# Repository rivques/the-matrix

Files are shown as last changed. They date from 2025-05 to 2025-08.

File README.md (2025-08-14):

# the-matrix



This is a large (theoretically 1ftx1ft) LED matrix display with a resolution of up to 120x120 monochrome pixels. My intended use for it is to act as an "ultra-clock," showing not just the time but also other useful information like weather, sports scores, maybe news, etc. However, it should be said that this is designed to be a generic module, and not destined for any specific project - this should be something I can pull off my shelf, send the correct control signals to, and get a display from.

I've had the ultra-clock idea for a while, and I originally wanted to use flip dots for the display, but they turned out to be expensive and hard to find, so I switched to using LED matrices instead.

The full display is constructed of 9 display modules, each of which itself contains 25 8x8 LED matrices. Each module also contains positions for the shift registers and MOSFETs that make up the control circuitry.

However, I have not yet built the full display - scaling up from 1 to 9 modules turned out to be _much_ harder than expected. I have 4 modules fully built, plus harnesses and a control board - I just haven't been able to make them play nice, despite spending more than 20 hours on scaling and troubleshooting. I still hope to realize the full vision at some point, but I'm pretty burnt out on this for the short term.

The display is not without its quirks. Most of these stem from either the geometric realities of trying to fit everything onto the board or a software-compensatable routing mistake that would take hours of work to fix in hardware. The biggest of these is that the current-limiting resistors aren't actually on the board but instead fly above the back of it. Also, the bottom and top row of matrices on each module are rotated 90 degrees, and every other module has pairs of rows and columns swapped (e.g. col1 connects to col2, col2->col1, col3->col4, etc.) This is something I can fix in software.

The display will probably be driven by a Pi Pico W or an ESP32, but especially if high framerates are not required it could be also driven by something less powerful. The driver connects to each row and column via the row control and column control pads.

One of the things I hope to learn from this board is where the limits actually lie when I try to drive things at high frequencies. I don't know how scared to be of things like ringing or EMI, and I'll probably find out.

The theoretical max framerate for this board is something like 4096fps, which would probably be implemented as 16fps with 255-tick BCM dimming, though this would require driving the clock line at something like 4MHz, and I have no idea if that'll be possible. If it's not, I can derate to something like 8fps with 7-tick dimming, which would be ~64fps or a much more manageable 60kHz clock frequency.

Here's a render of the back of the a single display module (the front is just a grid of matrices, which I don't have a 3D model for but I'm sure you can imagine). For more pictures, including the schematic and each internal layer, check out the [journal](https://github.com/rivques/the-matrix/blob/main/JOURNAL.md#may-29th).


BOM (for some parts I'm getting spares since they'd be a pain to source if some turn out to be dead on arrival. if this can't be included in the grant i'll happily cover the spares myself):

Part|Quantity|Price/unit|Total price|# pins/unit|# pins total|Note|Link
---|---|---|---|---|---|---|---
788AS 8x8 LED Matrix|230|$0.35|$82.00|16|3600|not going to count on 0% DoA rate here|https://www.aliexpress.us/item/2251832771187101.html
74HC595 Shift Register|15|$0.22|$4.00|16|240|2x20 is cheaper than 3x5|https://www.aliexpress.us/item/3256807421796895.html
TPIC6B595 Shift Register|20|$0.50|$10|16|240|again, not counting on no DoA|https://www.aliexpress.us/item/3256806981485001.html
IRFU9024NPBF MOSFET|125|$0.40|$40.00|3|360||https://www.aliexpress.us/item/3256808251284284.html
220Ω Resistor|120|$0.02|$2.80|2|240|2x100 is cheaper than 12x10|https://www.aliexpress.us/item/2251832766343175.html
2x20 right-angle header female|12|$2.00|$4.00|40|80||https://www.aliexpress.us/item/3256805899201197.html
2x20 right-angle header male|12|$2.50|$5.00|40|80||https://www.aliexpress.us/item/3256804718416281.html
5V 3A Power Supply|1|$4.00|$4.00|2|2||https://www.aliexpress.us/item/3256805577151044.html
Matrix PCB|10|$2.5|$25.00|0|0|i'll buy this separately from the grant so i can combine it with another order|JLCPCB
Total|||$173||4850|total w/o PCB: $148 :tada:

Schematic:


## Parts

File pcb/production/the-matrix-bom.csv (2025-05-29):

Id | Designator | Footprint | Quantity | Designation | Supplier and ref
1 | DS5,DS3,DS18,DS2,DS6,DS12,DS1,DS19,DS22,DS25,DS8,DS17,DS16,DS13,DS9,DS11,DS4,DS15,DS24,DS23,DS20,DS7,DS14,DS21,DS10 | DISPLAY_TA08-81GWA | 25 | TA08-81GWA
2 | Q13,Q6,Q26,Q39,Q36,Q11,Q22,Q38,Q33,Q14,Q5,Q15,Q10,Q28,Q17,Q21,Q34,Q31,Q9,Q24,Q3,Q16,Q4,Q29,Q25,Q30,Q37,Q1,Q7,Q18,Q8,Q32,Q40,Q27,Q20,Q19,Q12,Q23,Q2,Q35 | TO-251-3_Vertical_ThinPads | 40 | Q_PMOS_GDS
3 | U6,U8,U9,U10,U7 | DIP-20_W7.62mm | 5 | TPIC6B595N
4 | J6,J5 | PinSocket_2x20_P2.54mm_Horizontal | 2 | Conn_02x20_Odd_Even
5 | U3,U4,U1,U2,U5 | DIP-16_W7.62mm | 5 | 74HC595
6 | J4,J3 | PinHeader_2x20_P2.54mm_Horizontal | 2 | Conn_02x20_Odd_Even
7 | J2 | PinHeader_1x10_P2.54mm_Vertical | 1 | DNP
8 | J1 | PinHeader_1x13_P2.54mm_Vertical | 1 | DNP

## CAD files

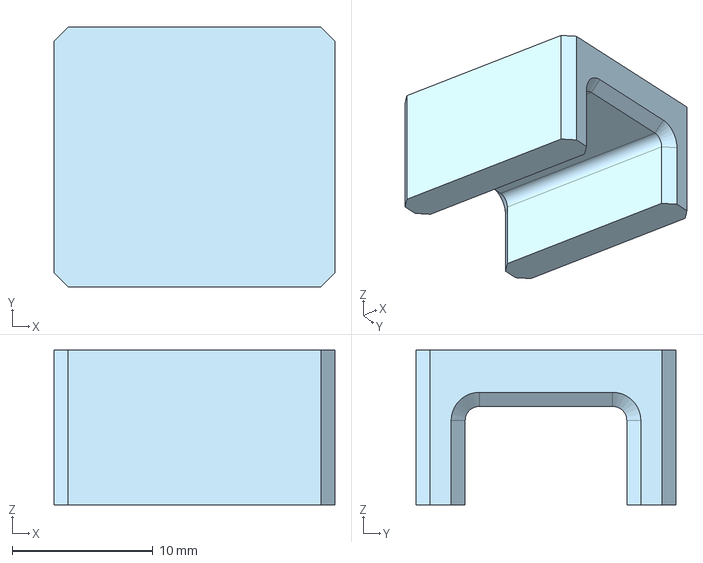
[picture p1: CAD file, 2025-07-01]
pcb/production/display_soldering_tool.step
20.0 x 18.5 x 11.0 mm

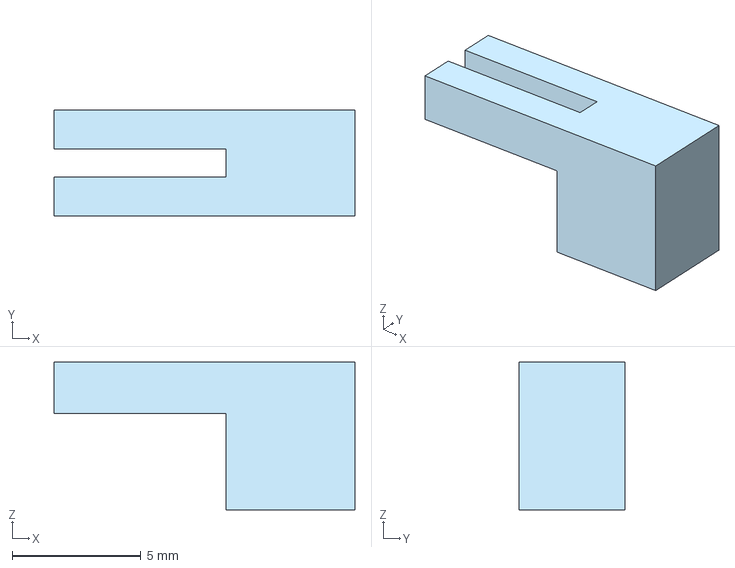
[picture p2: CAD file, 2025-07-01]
pcb/production/mosfet tool.step
11.7 x 4.10 x 5.74 mm

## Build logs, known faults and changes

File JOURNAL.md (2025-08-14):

---
title: "The Matrix"
author: "rivques"
description: "A large LED matrix to display things like the time, weather, sports scores, etc."
created_at: "2025-05-27"
---
## total time thru end of May: 17 hours
# May 27th:
Ok so this is something I've wanted to make for a while: a kind of "super-clock" that shows not just the time but also other relevant information. Initially I wanted to use flip-dot displays, but those are expensive and hard to find, so I'm pivoting to an LED matrix. I want to put a bunch of [these cheap 8x8 displays](https://www.aliexpress.us/item/2251832771187101.html) together, right now I'm thinking 30x30cm, which is 15x15=225 displays or 120x120=1440 pixels. The raw cost of those displays would be ~$80. I'm trying to figure out driver ICs. Ideally I'd like to solder everything myself, with no tiny SMD parts. One option is a bunch (30-450) of 74HC595s, depending on how many displays I want to be able to control at once. Let's take a second to do the math of how many LEDs/second I need to update to get, say, 10fps:
```numbat
let target = 10 fps
unit leds
let num_leds = 15*15*64leds
let leds_per_second = num_leds/frame*target
    = 144_000 leds/s
```
Okay. So say I go with the minimum of 30 74HC595s, and I update one column of the screen at a time. At 3V3 the max clock frequency is something like 25MHz, so let's see if 1MHz is enough:
```numbat
let clock_freq = 1 MHz
let columns_per_second = clock_freq/120
    = 8333 columns/s
let frames_per_second = columns_per_second/120
    ~70 fps
```
That's actually very good! And if I can actually hit 10MHz then I could get 700fps which might even be enough to do some PWM (BCM?) dimming, and that's assuming I have all the shift registers daisy-chained together and am not driving them in paralell. And another reason why that's great is that it makes my current needs low, if I'm only lighting a max of 120 leds at a time. So that would put my current needs at:
```numbat
let leds_per_column = 120 leds
let current_per_led = 12mA/led
let current_per_column = leds_per_column*current_per_led
    = 1.44 A
```
And since I'm only using one column at a time, that power is very manageable! I'll probably need to put a transistor on each column and row, because the 74HC595s can only source 6mA per pin, and I'd like to hit more like 12 or 14. So I'll need 240 transistors and 120 resistors, which won't be fun to solder, but shouldn't be too bad.

...

okay, i've done some more research, and it looks like it might make sense to switch to something like the TPIC6B595 for the low side, since it can sink enough current without needing a transistor. 

And then to fit it within the JLC PCB size I'll make a bunch of smaller boards that hook together with like right-angle duponts.

OK so here's what the major components are looking like right now:
Part|Quantity|Price/unit|Total price|# pins/unit|# pins total|Link
---|---|---|---|---|---|---
788AS 8x8 LED Matrix|225|$0.35|$80.00|16|3600|https://www.aliexpress.us/item/2251832771187101.html
74HC595 Shift Register|15|$0.22|$4.00|16|240|https://www.aliexpress.us/item/3256807421796895.html
TPIC6B595 Shift Register|15|$0.50|$7.50|16|240|https://www.aliexpress.us/item/3256806981485001.html
IRF9520 MOSFET|120|$0.40|$48.00|3|360|https://www.aliexpress.us/item/3256806868594722.html
220Ω Resistor|120|$0.02|$2.80|2|240|https://www.aliexpress.us/item/2251832766343175.html
5V 3A Power Supply|1|$4.00|$4.00|2|2|https://www.aliexpress.us/item/3256805577151044.html
Matrix PCB|10|$2.20|$22.00|0|0|JLCPCB
Total|||$164||4700|

Okay, $164 isn't terrible. What I'm more concerned about is 4700 joints, that'll take a while. Rounding up to 5000 for the connectors and stuff, if I can do 40 joints per minute (optimistic), that'll take:
```numbat
unit joints
5000 joints / (40 joints/minute)
    = 125 minutes
```
...that's not as bad as I thought. It'll probably end up being twice that, but I was afraid it'd be something like 40 hours. This project seems feasible!

**total time spent (estimate): 2.5 hours**: 

# May 27th, part 2:
OK i'm going to sit down and try to work out a schematic. I also realized that I needed to switch to a P-channel MOSFET for the high side, which I changed in the BOM.

[much later]

ok so there's a schematic now. i decided im not going to have a separate PCB for the control board, i'll just do that on perfboard. (again, bom has been updated). so now the plan is to make 9 (well, 10, because of JLC order sizing) boards to _almost_ the schematic. each board will be populated with its 25 displays and the 4 40 pin connectors, and then one board in each row/column will have that row/colum's driving circuitry. Then the board with driving circuitry will be connected to the control board, which will have a pi pico w on it. next up: routing this monstrosity. i'll have to make sure i don't make impossible sandwhiches, but other than that it shouldn't be difficult, just tedious.

## screenshots

## close-up on one matrix and drivers


**total time spent (estimate): 3 hours**

# May 27th, part 3:
start time: 11pm

ok i'm going to start on the pcb layout. I'm not ghoing to try to do routing tonight, but i do want to at least get the rough positions of things figured out.

ok, i'm about 30 mins in, and its becoming clear that i have to rotate the top and bottom rows of displays 90 degrees so i can fit the row connectors in. this will cause some headaches when doing the firmware, but i don't think i have a choice. this is what it's looking like now:



ok now for the (hopefully easier!) task of shoving all the ics and mosfets under the displays.

...and i'm realizing that there's no way to do this without 4 layers. fortunately it's not that much mre expensive.

30 more minutes later, these mosfets are just way too big. i'm going to switch to the [IRFU9024NPBF](https://www.aliexpress.us/item/2251832086805199.htm), which is actually cheaper than my original option, and it's in the smaller TO-251 package.

...it's been another 30 minutes, and i've gotten everything placed, thanks to the smaller mosfets. here's what it's looking like:



and that may not look terrible, but keep in mind that almost every empty pad is going to have an led matrix in it from the other side, and that's not even considering the traces between the near-1000 pads on this board. if this is possible, it's possible by the slimmest of margins.

**total time spent: 1.5 hours**
**total time on May 27th: 7 hours**

# May 28th:
Start time: 9am
Okay I'm starting to route the rows to each other. I'm changing the footprint of the mOSTFETS slightly to allow a trace to fit between their pads.

[one hour later]

so i've gotten the middle rows and the rght column and a half routed. it's difficult but not impossible. the top and bottom rows are going to be a massive pain since they're rotated.

[another hour later]

Ok, i have all of the matrices routed, using just the internal layers. I haven't routed the connectors or drivers yet, but hopefully the outer layers are enough room for that. here's what it looks like now:



**total time spent: 2 hours**

# May 28th, part 2:
Start time: 2:45pm
I'm going to start routing the connectors. Hopefully I can stay on the interal layers, but I'm okay to use the outer ones sparingly.

[one hour later]

okay, one connector and some of the mosfets are routed. i've needed the outer layers 3 times so far - not as bad as I was expecting!

[another hour later]

ok, another connector and the rest of the mosfets' column connections are routed. next up: the row connectors.

...this is _really_ annoying routing.

...ok i've routed the left row connector. i'll do the right one later.

**total time spent: 2.5 hour**
# May 28th, part 3:
Start time: 8:30pm
ok time to do the last connector and then hopefully the last part won't be that bad.

[30 minutes later]

i've just realized that i set up the connectors wrong in the schematic, so row 1 would connect to row 2 and vice versa, row3<->row4, etc, same with columns. either i can give up the past 3 hours of work, or i can spend a similar amount of time fixing that in software. let me think for a second about that:
ok so the way this would manifest is just in the display, it wont cause any electrical issues fortunately. it'd just be that the middle row/column of matrices would have their column pairs swapped with each other. i wonder how i can efficiently represent that in software.

well i'm going to have to have a preprocessing step for every frame i want to display. and i'll leave it up to later me to figure out what the best way to swap the columns and rotate the displays is there, i'd rather spend 3 hours programming than 3 hours rerouting stuff i've already done once, and it'll hopefully take less than 3 hours to fix. it's unfortunate, but oh well.

anyways back to routing the last of the right connector, yipee!

[another 30 minutes later]

ok, all connectors complete! now the only thing left is just hooking up the shift registers, and i have almost all of the outer layers to make it happen. here's how it's looking now:



ok now i'm going to hook the mosfets up to the shift registers

[30 minutes later]
ok the mosfets are connected to the low-shift registers. now i need to connect the rows to the low-side shift registers, connect the shift register data lines to each other, and give power to everything.

[15 mins later]

all shift registers are connected to their matrices/mosfets. next: data lines.

[15 mins later]
ok the low-side data lines were pretty quick, because there's patterns between the chips. i've done the data lines on 1 high-side driver and they were super annoying - they're long and there's no patterns from chip to chip. i'm going to call it a night.

**total time spent: 2 hours**
**total time on May 28th: 6.5 hours**
# May 29th:
Start time: 9am
Time to finish up the data lines.

[45 minutes later]

That wasn't so bad. Now my only remaining unrouted nets are power and ground!

[30 minutes later]

ok, power and ground are routed, and I learned that fills don't need pre-existing traces in order to automatically connect to nets, so that saved me a lot of work. Time to run DRC and see how bad everything is.

...413+ errors. oh boy.

okay, so ~200 of those were because i'd input the JLC via size constraints (confused via diameter with annular width), so those went away. Most of the rest were because of me putting pads under the displays, which was by design. Then there were a few which were about short traces being unconnected, which I'm ignoring, and a bunch of silkscreen overlap, which I will now go fix.

WAIT I RAN THE SCHEMATIC PARITY CHECK AND SOMEWHERE ALONG THE WAY I FULLY DELETED A DISPLAY
ok time to trawl thru the git history and find when that happened

ok it was in the last commit so hopefully i can just put it back and things will be fine

yeah it turned out fine. i must have deleted it right before running drc. phew.

anyways time to go mess with silkscreens

[30 minutes later]

ok, I _think_ the board is complete! Here are some screenshots:
||
---|---|---
||
||

going to export the gerbers and get a real price!

ok so it's $9 for the boards (with a coupon), plus $16 shipping. i can't believe how cheap JLC is.

and just going to do a revised bill of materials here:
(for some parts I'm getting spares since they'd be a pain to source if some turn out to be dead on arrival. if this can't be included in the grant i'll happily cover the spares myself)

Part|Quantity|Price/unit|Total price|# pins/unit|# pins total|Note|Link
---|---|---|---|---|---|---|---
788AS 8x8 LED Matrix|230|$0.35|$82.00|16|3600|not going to count on 0% DoA rate here|https://www.aliexpress.us/item/2251832771187101.html
74HC595 Shift Register|15|$0.22|$4.00|16|240|2x20 is cheaper than 3x5|https://www.aliexpress.us/item/3256807421796895.html
TPIC6B595 Shift Register|20|$0.50|$10|16|240|again, not counting on no DoA|https://www.aliexpress.us/item/3256806981485001.html
IRFU9024NPBF MOSFET|130|$0.40|$50.00|3|360||https://www.aliexpress.us/item/3256806868594722.html
220Ω Resistor|120|$0.02|$2.80|2|240|2x100 is cheaper than 12x10|https://www.aliexpress.us/item/2251832766343175.html
2x20 right-angle header female|2|$2.00|$4.00|40|80||https://www.aliexpress.us/item/3256805899201197.html
2x20 right-angle header male|2|$2.50|$5.00|40|80||https://www.aliexpress.us/item/3256804718416281.html
5V 3A Power Supply|1|$4.00|$4.00|2|2||https://www.aliexpress.us/item/3256805577151044.html
Matrix PCB|10|$2.5|$25.00|0|0|i'll buy this separately from the grant so i can combine it with another order|JLCPCB
Total|||$173||4850|total w/o PCB: $148 :tada:

i think this is almost ready to ship!  
**total time spent: 3.5 hours**

# June 26th:
Start time: 4pm

OK some of the parts have started to arrive. I'm realizing I'm going to need to make a tool to hold the displays in the right place while I solder them, so I'm going to grab the 3D model and throw it in Onshape and see what I can do.

ok, i've got the model in Onshape (and I added a model of the matrix module itself), and I've started to sketch out a magazine page. The holder will have to wait for tomorrow.

**total time spent: 1 hour**
# June 27th:
Start time: 11:15am

just nearly finished the magazine page. it took a while but i'm not used to figma. one weird thing i ended up doing was to get a render of the board with a transparent background, I rendered it in KiCad, then remove the background with remove.bg, but that only gave a low-quality version, so I pulled it into GIMP, and used the transparency as a mask on the high-quality render.

**total time spent: 1 hour**

# June 30th:
Start time: 4pm

All my parts arrived!

I 3D printed some little feet that I can use while soldering to hold the board at the correct height. 

I'm going to start by soldering the bare minimum support components for a single display (DS1) and go from there. That includes, in order:

- U1
- U6
- Q1-Q8
- DS1
- R1-R8

Hmm, by not doing the whole board at once I'll make it much more annoying to solder the rest of the backside components. I think it's worth it to be able to test the first display, though. 

As a side note, the order for an entire module will be:
- U1-U5
- U6-U10 (with outputs cut)
- J1-J6 as needed
- Q1-Q40
- DS1-DS25
- R1-R40

[45 mins later]
aaa i forgot to cut the outputs on U6, so i've had to cut the physical traces, which is luckily possible but is still a pain.

[45 mins later]
i'm almost there! i've just got 3 jumper resistors left, which are, predictably, the most annoying part. i don't look forward to doing 115 more of them.

**total time spent: 1.5 hours**

# June 30th, part 2:
Start time: 9:45pm

time to solder the last 3 resistors, then i'll write some test code

[30 mins later]  
resistors soldered! behold (but not too closely):  


ok tomorrow we wire it up and start testing!  
**total time spent: 30 mins**  
**total time on June 30th: 2 hours**  

# July 1st:
Start time: 12:30pm

time to start on code. i'll start with full software driving, not PIO, while i test things at low FPS.

[an hour later]

i've wired everything up and written some test code and... it's not working. it seems like i'm doing something wrong with at least the low-side shift register, because when i short one of its outputs to ground i do get leds turning on. the voltages on its output pins are either 5 volts (which is reasonable for open-drain state) or 3 volts (which is not reasonable, especially if that's it trying to sink current). it's not unlikely that i broke the chip while soldering, but i'm hoping it's not that. i'm going to write a super simple test program and try to isolate the problem.

[45 mins later]  
so there's also something wrong with the high-side. i'm focusing on that one first - it seems to be totally unresponsive to my commands.  
i found it - i just miswired the column control header. hopefully that fixes many of the problems.
and also it looks like i've partially miswired the row control header as well.

[15 mins later]  
ok, rewiring complete, and it looks like that helped a lot, but not all the way. going to keep messing with the test program.

[15 mins later]  
ok i think i've isolated the issue to the low side. (column 3 has a bad solder joint too, but that's not the main issue). for some reason, the shift register just isn't listening to me. i'm going to take a break, but I think the next step is to triple-check the pinout and then the datasheet if that doesn't work.

**total time spent: 2.25 hours**

# July 1st, part 2:
Start time: 6pm

no apparent wiring issue. time to check the datasheet.  
i see a problem! in the schematic, I mixed up RCK and SRCK (labeling them as ROWCLK and ROWLATCH instead of the other way around). Let me try swapping them back in my wiring...  
progress! now one row of LEDs lights up!  
AND IT ALMOST FULLY LIGHTS WHEN I RUN THE RIGHT TEST CODE!

the one remaining issue is that COL3 isn't illuminating. I'm going to reflow the solder joints really quick and see if that helps.  
it didn't fix it. Time to play more of everyone's favorite game "where's the voltage?"  
...actually, i just reflowed the wrong joint. Reflowing the correct joint fixed it!

ok, time to test some other stuff. First up: PWMing the ROWEN pin for global brightness control.  
...yep, works perfectly.

briefly, here's the current list of the various ways in which this is janky:
- need to use 3D resistor technology to connect the low side shift registers
- need to use display height jigs + solder from top to fit around the expansion ports
- row latch and clock pins are the wrong way around on the schematic

next: try to drive it in PIO, and hopefully fix some of the flickering i'm seeing which I assume is from micropython's garbage collection or similar.

... no luck on the first attempt at PIO, but there's so many things that could be wrong. I'm going to pare it down to a minimal example and build it back up.

... ok i worked out a bunch of bugs. now the only thing left is something weird with the ring size parameter on the DMA. maybe i need to align the buffer to memory or smth? anyways its a problem for later. one thing that helped a lot was putting LEDs on most of the outputs so I could see what I was trying to do. then it was just a matter of tweaking the various parameters of the PIO stuff (set_init ordering, transfer size, byte swapping, etc.) until it worked.

**total time spent: 2.5 hours**

# July 1st, part 3:
Start time: 10:30pm

Against my better judgment I'm going to keep working on this tonight. I have some ideas for how to fix the ring size issue.

[30 mins later]  
IT WORKS! like, fully works! the trick was to just have an interrupt run whenver the DMA write was done that immediately restarted it. I ran into some weirdness where the board refused to enumerate on USB once I uploaded the file, but a flash_nuke.uf2 fixed that. Now to see how far I can push the PIO frequency...  
looks like 2MHz has some slight ghosting - like the rows stay on for a little while the next column is written, but 1MHz is fine. Working backwards, that equates to:
```numbat
let pio_clk = 1MHz
let col_rate = pio_clk/52
let full_bw_rate = col_rate/120
    = 160 fps
```
That's... a little lower than I hoped. It means I might not be able to get any greyscale values without getting flickering. But there's definetly room for optimization, I bet if I adjust the timings in the PIO program I can figure out which delay is critical to eliminating ghosting and which I can speed up. Now, though, I think the next step is to solder up another matrix module and try to get two working together. This is looking really promising!

**total time spent: 30 mins**
**total time on July 1st: 5.25 hours**

# July 2nd
start time: 3:30 pm

OK with yesterday's success I'm going to solder the rest of the high-side components to expand to a 8x40 display.

[1 hour later]

that was 32 transistors, 4 shift registers, and 4 displays in ~1 hour, or a little under 4 joints per minute. That's a bit slow, but hopefully working in bigger batches will help.

Now, i'm going to adjust the code to account for the 32 new columns, which should be pretty trivial

[1.25 hours later]
...it was not pretty trivial. there were a few solder joints i needed to reflow, but then micropython started being weird - like claiming the pio was running, then not actually running it except for the 0.1secs when i pressed ctrl+c, and disconnecting from the repl fixed the issue.

[15 mins later]

i spent some time trying to make a function to draw a framebuf on the screen, but i had a bad approach. i'll try again later.

**total time spent: 2.5 hours**

# July 9th:
Start time: 1pm

The goal for today is to get one full module working. So I need to solder:
- U7-U10 (with outputs cut)
- J5 and J6
- DS10-DS25
- R9-R40

[4 hours later]

soldering complete! again, the resistors were incredibly annoying. I do think it won't be _that_ bad to solder the non-row-control modules.

Going to update the code to use a 40x40 display, and see how it works.

[1 hour later]

updated the code, and it mostly works! there's a few display joints that need reflowing, some of which will be a massive pain to reach, but by and large it works! next: figuring out what transform each display needs to be in the right place. 

[another hour later]

got all the pins reflowed! there's some glitchiness with some pixels flickering, not sure why that is yet. my next step is probably to try and optimize the framebuf->pio data step - right now it takes 1700ms(!) and if i can get that to like <50ms then i can do some animations.

here's what it looks like now:  


**total time spent: 6 hours**

# July 10th:
start time: 11:30am

I'm trying to optimize the frame computation. So far I've gotten it from 1700ms to 450ms by precomputing the transformation from display x/y space to bit in framebuf. I shaved off another 50ms by adjusting for loops to move through the LUT sequentially. Finally, I got down to ~325ms by using the `@micropython.native` decorator, which is very cool. I might be able to get a little more if I made the function work with the `viper` optimizing compiler. I think that's the end of the easy wins, though. If I want, say, 50ms, then each pixel would only get 7 instructions to deal with, and that's if I overclocked to 200MHz. That seems unfeasible. Part of what makes this difficult is that it's hard to operate on more than 1 bit at a time. I can't operate on, say a byte of the framebuf (an 8-pixel row of the display) at a time, because the PIO needs column-first indexing, so I'd span 8 columns. Even if I switched the framebuffer format to column-first, I'd still have issues because adjacent pixels end up in separate PIO words. I think maybe I need to admit that I won't get realistic realtime frame computation, so I'll need to precompute frames that need to play at more than 2fps. That'll cost (16 bytes per column * 120 columns) = a little under 2 KiB per frame. With a `gc.collect()`, the board reports ~160 KiB free, or 80 frames. Not sure how much of that will end up taken by the networking stack, but even so, I can't think of many clock faces that would even need precomputation, and those that do wouldn't need more than ~10. So this should be fine.

As an aside, I'm getting an understanding for how a GPU gets its speedup. This pixel-by-pixel work is so succeptible to parallelization (on a per-column basis at the very least), but I don't have 120 cores handy to do it.

**total time spent: 1 hour**

# July 22nd:
Start time: 11am

Getting back to this project after Undercity, I'm going to solder another display module, to be attached horizontally. This means I'll need to solder:
- U1-U5
- J2, J4-J6
- Q1-Q40
- DS1-DS25

[2 hours later]

I finished the module! I haven't tested it yet, though. It looks like I didn't quite judge the spacing right on the inter-module connectors, there's ~1px of space between modules. Also, I was doing some more theorizing about the max frame computation speed - that 7 cyc/pixel number is way off, at 50ms frame times it's more like 350cyc/px, which is much more manageable.

**total time spent: 2 hours**

# July 23rd:
Start time: 1:30pm

Going to see if the new module works.

[30 mins later]

ok i keep trying to wire these jumpers onto a breadboard and it's so messy and i keep miswiring things. i'm going to start on the control board for the real thing so i can do the wiring once and for all.

ok so here are the connections:

pin | # connections
---|---
5V | 6-12
GND | 12-18 (bc colen is pulled low)
CLR | 6
LATCH | 6
ROWEN | 3
ROWCLK | 3
COLCLK | 3
COLDAT | 1
ROWDAT0-14 | 1 each

i'm going to have to do splices for the main lines, there's no way i'm running 50 wires back to a control box.

ok time to go sketch 

something like this?



not sure how i'm going to mount these yet. maybe i'll make a backplane that uses the gap between modules and hooks onto the connectors? btw i weighed a module and it was 144g.

oh also maybe i could use those 40-pin connectors i have for the connections to the controller?

** total time spent: 1 hour**

# July 24th:
Start time: 12:30pm

Going to design the wiring harness that will connect the modules to the controller. 
So the row harness will run vertically down the side of the display and will carry 22 wires. It'll connect to the controller with a spare 2x20 header, and will branch into three 1x12 headers for the three rows. The following lines will be spliced so all modules share them: 5V, ROWCLK, CLEAR, LATCH, ROWEN, and 2xGND. Then each connector will also get 5 ROWDAT lines. The column harness will have a similar, but simpler structure. It'll connect to the controller with a 1x8 header, and will branch into three 1x10 headers for the three columns. The following lines will be spliced so all modules share them: 2x5V, COLCLK, CLEAR, LATCH, and GND. The COLDAT line will be daisy-chained along the harness. The COLEN pin will be tied to the other GND pin at the header. 

**total time spent: 30 mins**

# July 26th:
Start time: 10:45am

Pinout for row connector:
1|2|3|4|5|6|7|8|9|10|11|12|13|14|15|16|17|18|19|20
---|---|---|---|---|---|---|---|---|---|---|---|---|---|---|---|---|---|---|---
ROWEN/GP0|ROWDAT0/GP1|GND|ROWDAT1/GP2|ROWDAT2/GP3|ROWDAT3/GP4|ROWDAT4/GP5|GND|ROWDAT5/GP6|ROWDAT6/GP7|ROWDAT7/GP8|ROWDAT8/GP9|GND|ROWDAT9/GP10|ROWDAT10/GP11|ROWDAT11/GP12|ROWDAT12/GP13|GND|ROWDAT13/GP14|ROWDAT14/GP15
5V|NC|NC|NC|NC|NC|NC|NC|NC|NC|NC|NC|NC|NC|NC|ROWCLK/GP19|CLEAR/GP18|NC|LATCH/GP17|NC

Pinout for column connector:
1|2|3|4|5|6|7|8
---|---|---|---|---|---|---|---
COLDAT/GP16|LATCH/GP17|GND|CLEAR/GP18|NC|COLCLK/GP20|5V|5V

Other connections:
- 5V rail to pico VSYS
- GND rail to pico GND
- Power jack to power rails

[1:45 later]
protoboard complete (except for the power jack). I think what's next is just grinding through the rest of the modules.

Just gonna paste the order of operations here:
- U1-U5
- U6-U10 (with outputs cut)
- J1-J6 as needed
- Q1-Q40
- DS1-DS25
- R1-R40

**total time spent: 2 hours**

# July 26th, part 2:
Start time: 4:30pm

[1.5 hours later]
All done with the (0, 1) module except for the resistors. After that, I get to do my first driverless module, which will be interesting.

**total time spent: 1.5 hours**
**total time on July 26th: 3.5 hours**

# July 28th
Start time: 11am

Time to grind through a bunch of modules. Resistors, then the first driverless module, then the (2, 0) column driver, then another driverless.

[2 hours later]

That was an annoyingly long time soldering resistors. Hopefully the rest will go faster.

[1 hour later]

Driverless module complete. Time for the harness, forr real this time,.

[1.5 hours later]

Column harness wires stripped and soldered, with one connector out of 4 complete. 

**total time spent: 4.5 hours**

# July 29th:
Start time: 9am

Adding the connectors to the column harness.

[1 hour later]

Column harness complete! Time for the row harness.

[3 hours later]

Row harness nearly complete - just need to solder the 1x12s. Then, _hopefully_, I can just plug in the display modules and it will Just Work.

**total time spent: 4 hours**

# August 9th
Start time: 11am

Time to solder the last of the row harness.

[1 hour 45 minutes later]

Row harnesses complete. When we come back: moment of truth.

**total time spent: 1 hour 45 minutes**

# August 10th
Start time: 10:45pm

It's not working, the second column is full on. 

[15 minutes later]

I've switched the COLEN and the COLDATOUT pins on the harness connectors. I'll have to re-solder them and deal with how to tie COLEN low. That'll be really annoying.

**total time spent: 15 minutes**

# August 11th
Start time: 12:45pm

I've swapped the COLDAT lines to the correct pins on the harness connectors, and tied COLEN to GND with bodge wires on each board. I also fixed a few other bad solder joints on the connectors - I really wish I'd designed this in a way that let me use an off-the-shelf harness to connect things. I'm still having issues. Something is wrong with the communication to the row controllers - the specific row data isn't being received correctly, regardless of clockspeed. rows 0-3 on each module are either all on or all off depending on what the majority of the bitmap is, and row 4 is doing its own random thing.

I'm pretty close to burning out on this project, I've been in the trenches for so long and I haven't gotten any new things working for more than a month - I've just been laying the groundwork needed for scaling. 

**total time spent: 1 hour**

# August 13th
Start time: 11:45am

I'm going to reduce scope to just one module so that I don't burn out and so that I have something to submit. This should be as easy as just running my existing code.

[1 hour 45 minutes later]



I got it working again! One of the things I forgot about was mixing up latch and clock signals, so once I fixed that I was able to do a bit of programming to allow displaying successive frames and it pretty much just worked.

Next: a last-ditch attempt to make the 4-module version work.

**total time spent: 1 hour 45 minutes**

# August 13th, part 2
Start time: 7:15pm

Ok, perhaps ill-advisedly, I'm going to try to scale back up to 2x2. But I think I know what the issue was this time: ROWCLK and ROWLATCH being swapped. To fix this, I'm re-solder the protoboard to swap that back.

[30 minutes later]

All boards light, but the 3 off-main ones definetly are not healthy. There are soooo many things that could have gone wrong there, and I don't think I have time to figure out which one.



**total time spent: 30 minutes**
**total time on August 13th: 2 hours 15 minutes**

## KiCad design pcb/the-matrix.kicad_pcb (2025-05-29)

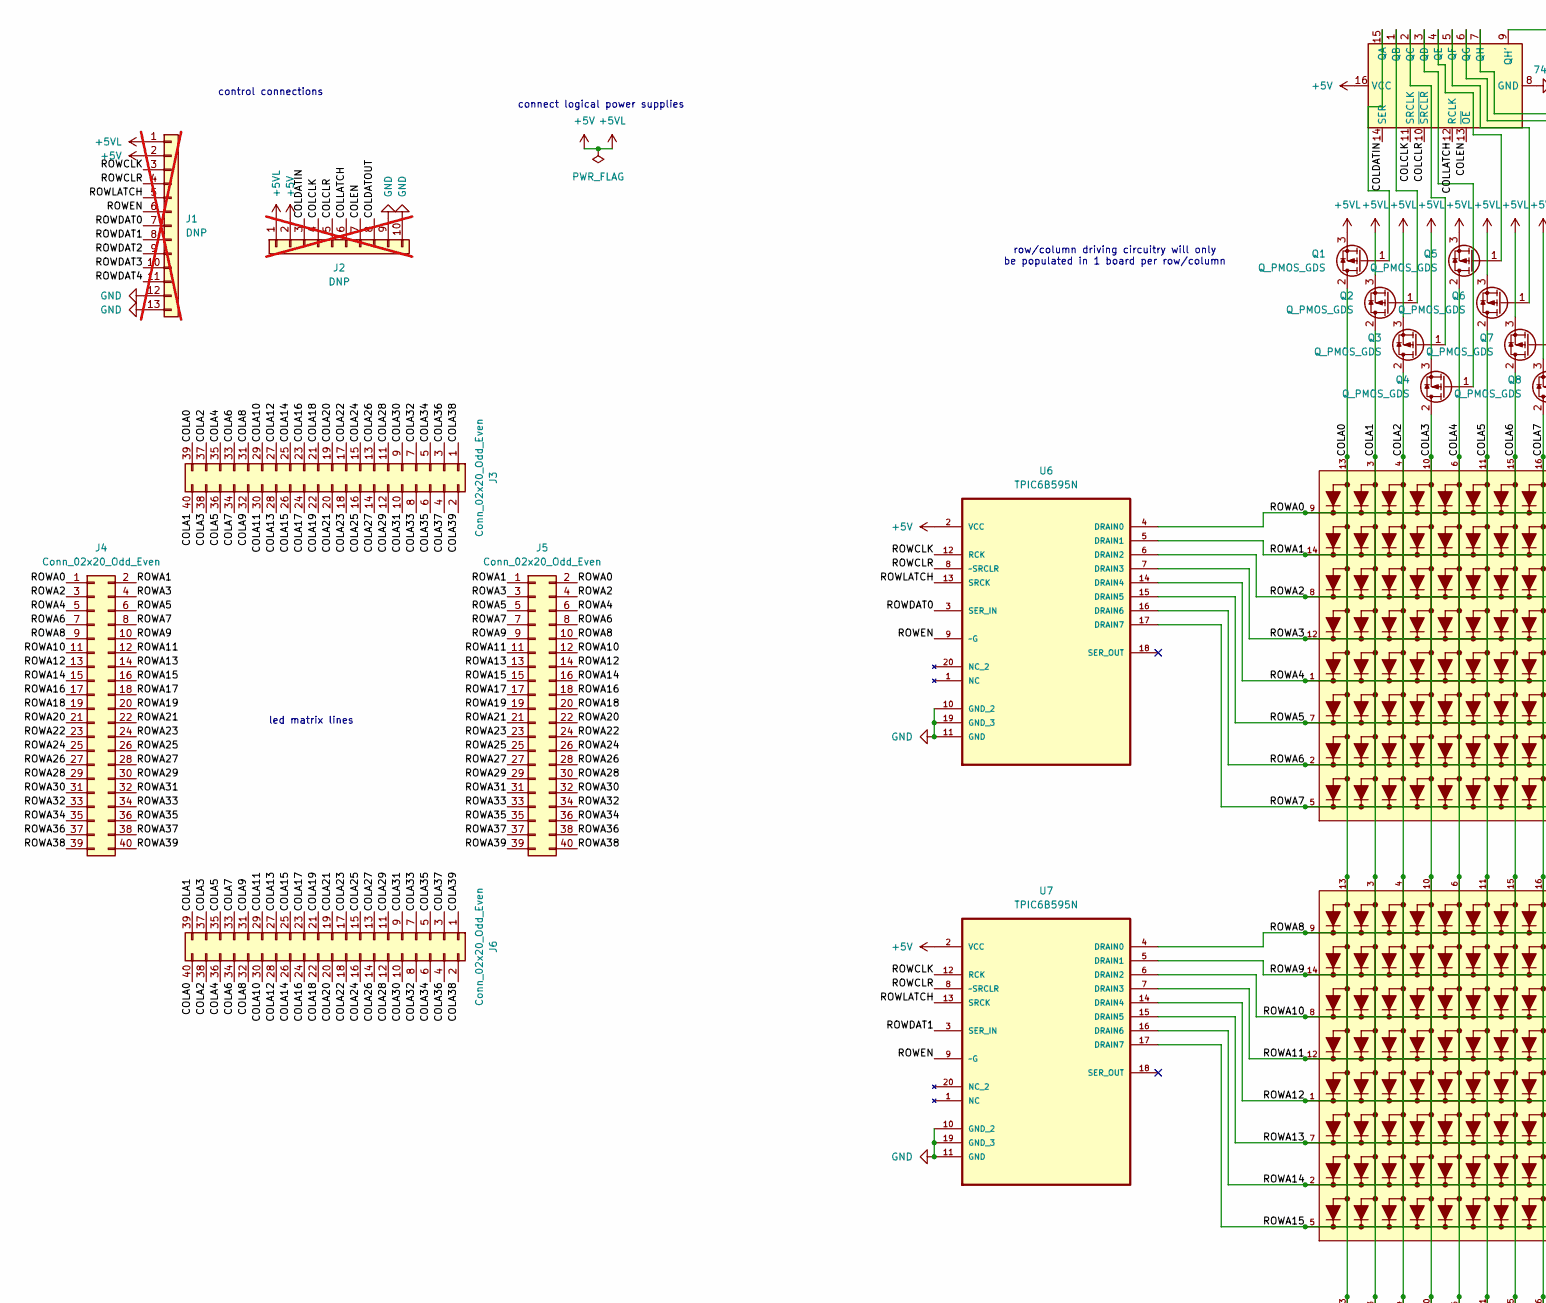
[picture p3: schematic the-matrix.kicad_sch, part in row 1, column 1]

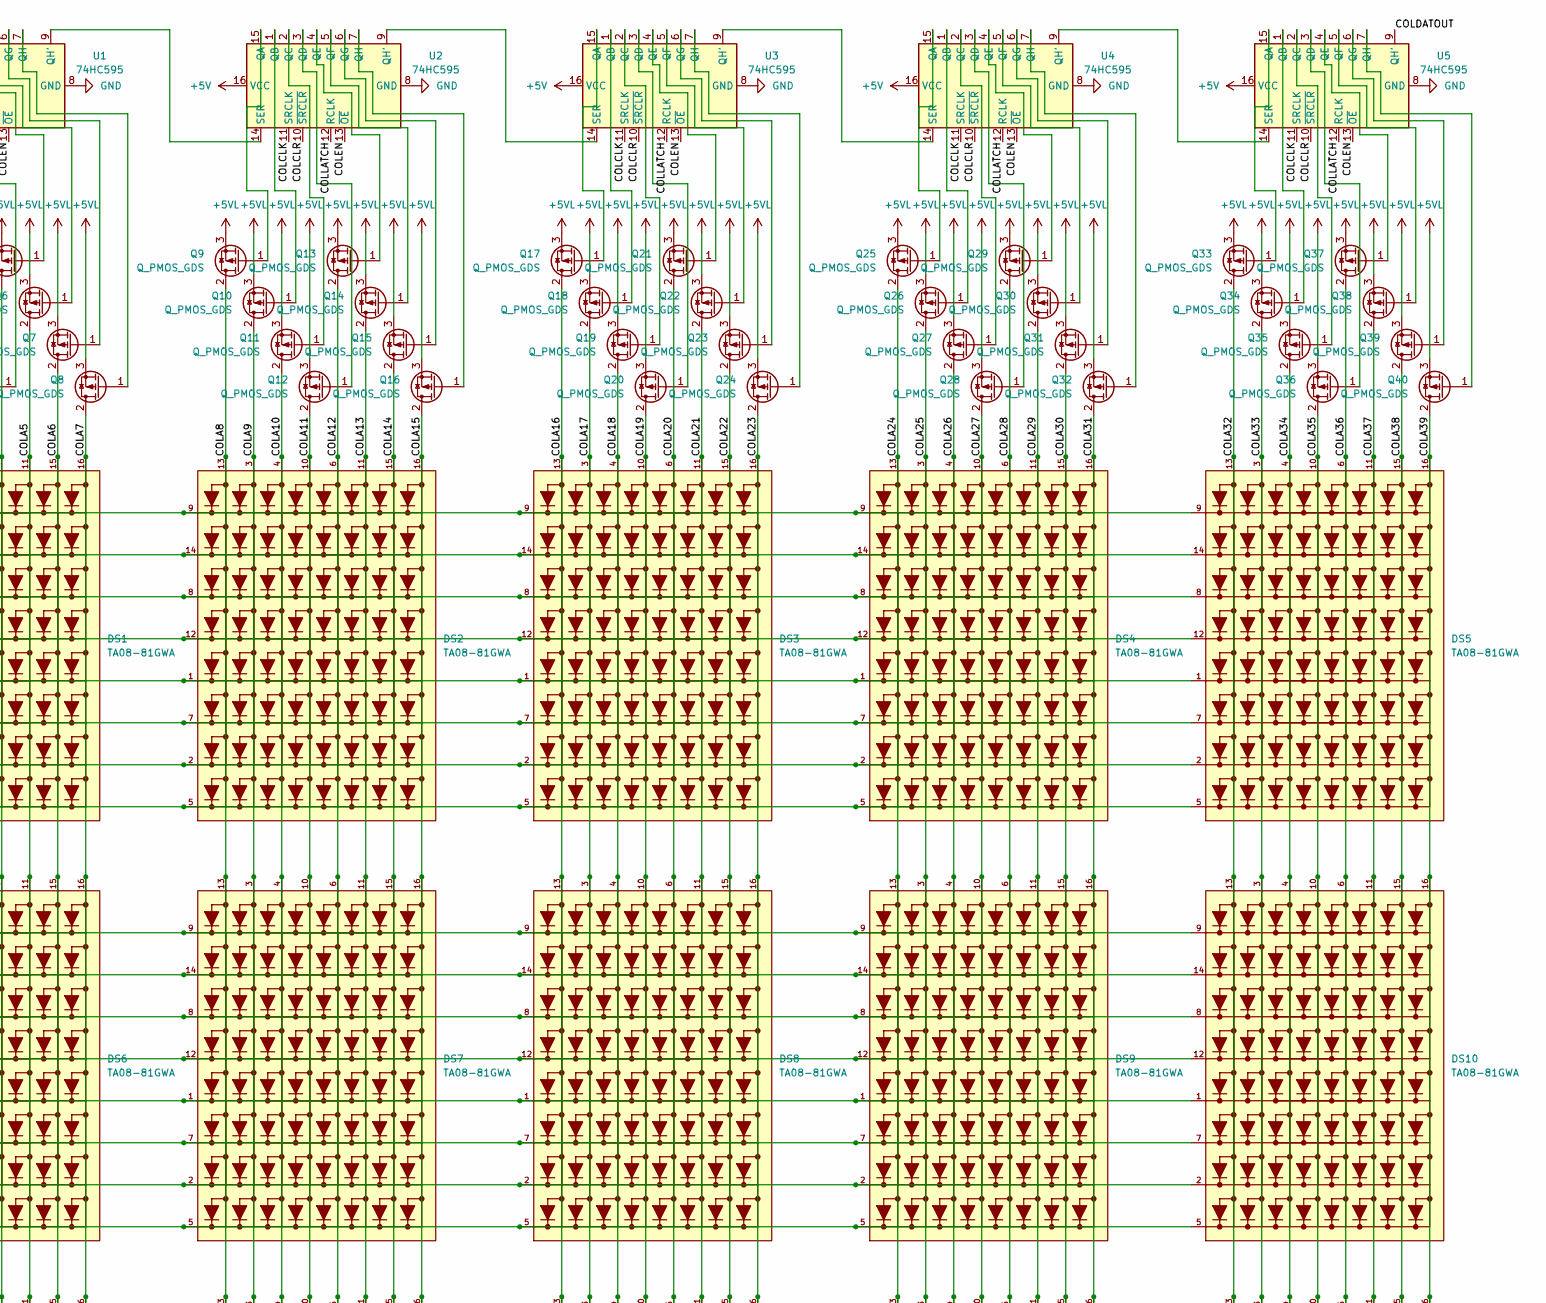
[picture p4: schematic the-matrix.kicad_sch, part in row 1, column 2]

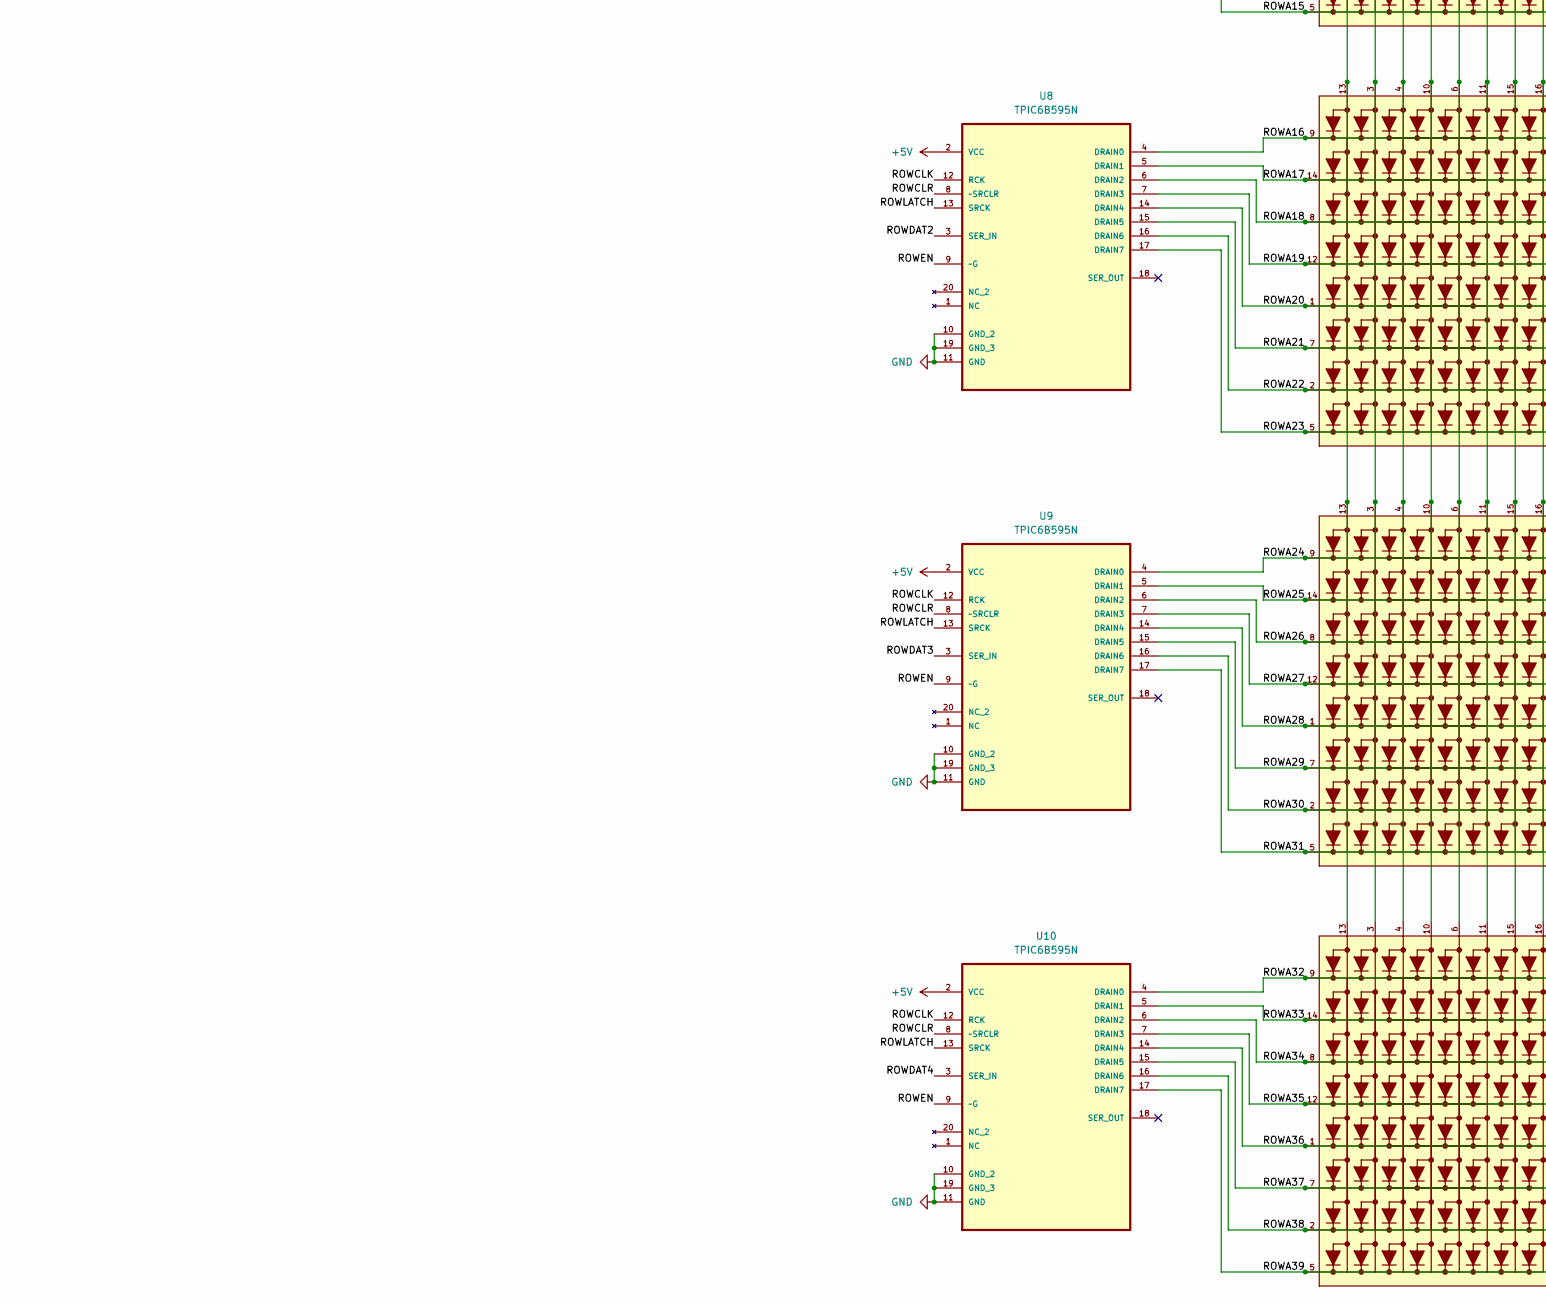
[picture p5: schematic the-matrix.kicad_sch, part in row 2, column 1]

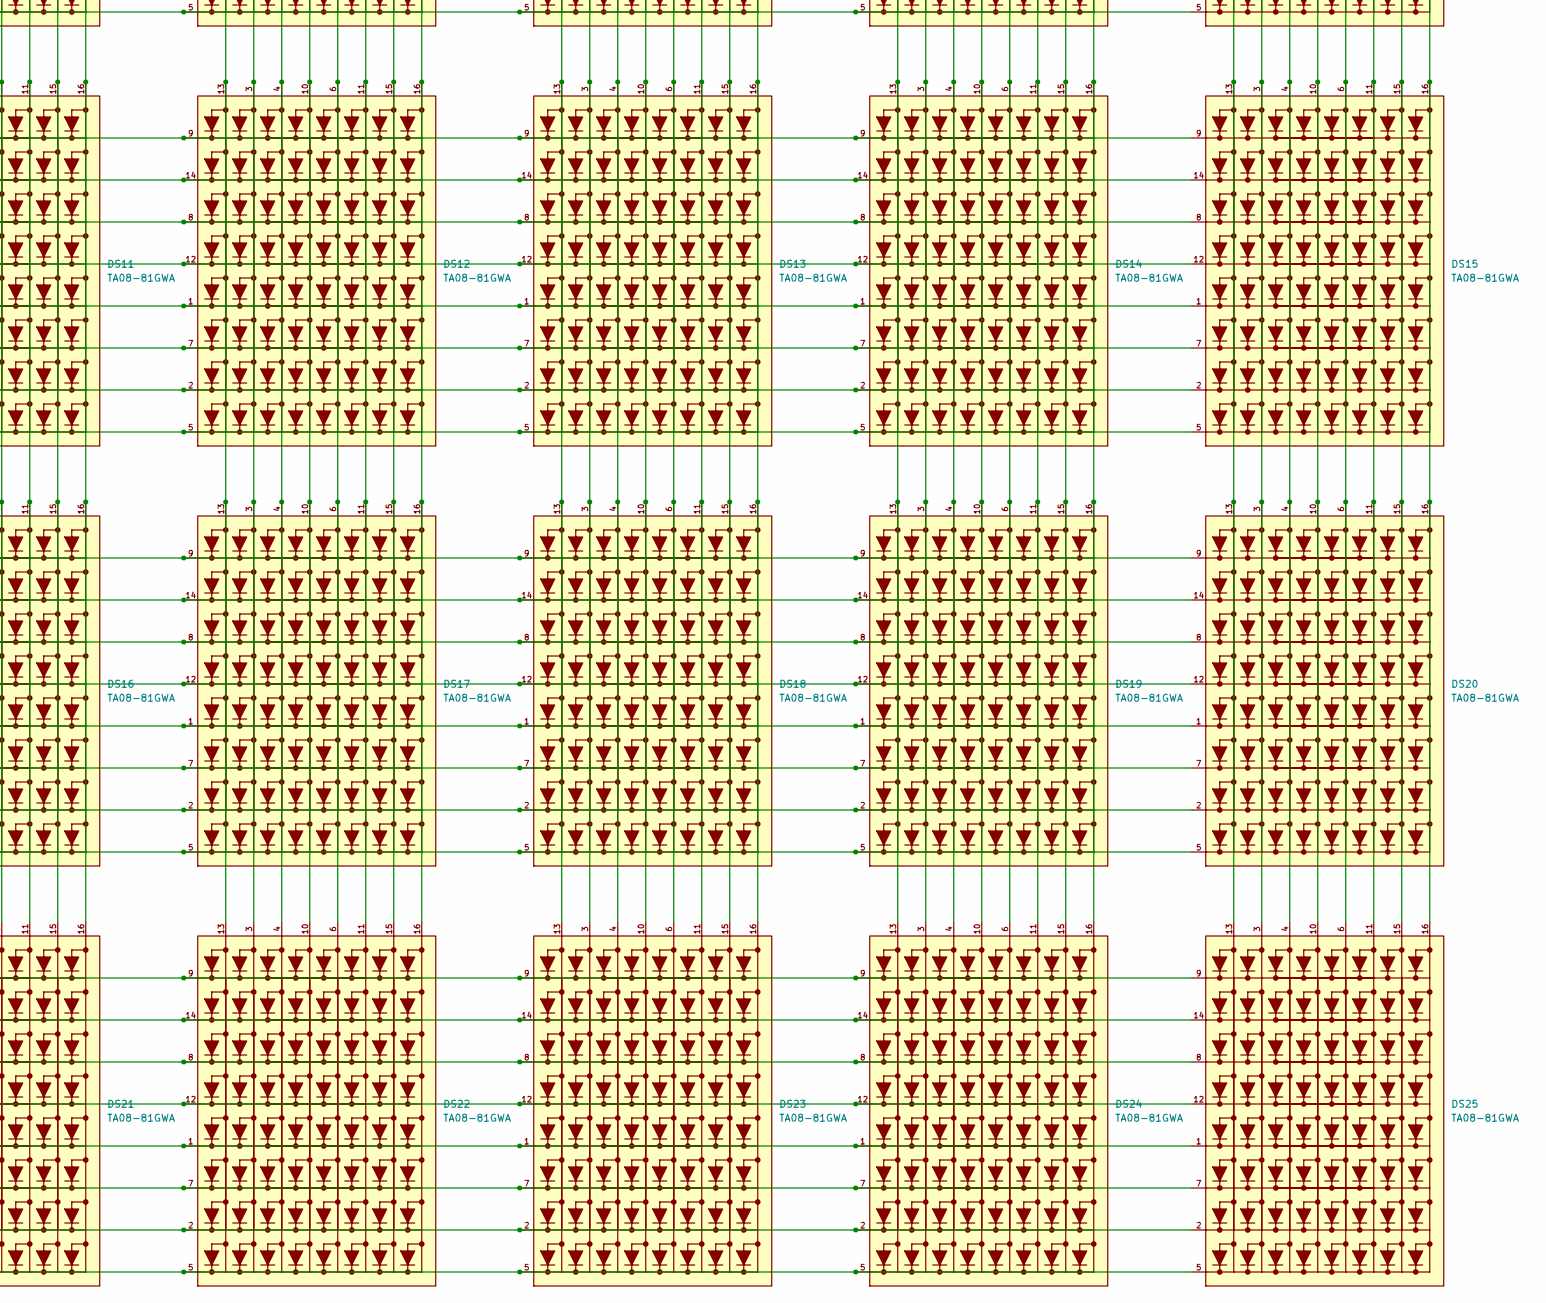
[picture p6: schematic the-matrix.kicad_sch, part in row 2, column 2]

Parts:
DS1, DS2, DS3, DS4, DS5, DS6, DS7, DS8, DS9, DS10, DS11, DS12, DS13, DS14, DS15, DS16, DS17, DS18, DS19, DS20, DS21, DS22, DS23, DS24, DS25: TA08-81GWA; DISPLAY_TA08-81GWA; PARTREV V.11A
J1: DNP; PinHeader_1x13_P2.54mm_Vertical; not fitted
J2: DNP; PinHeader_1x10_P2.54mm_Vertical; not fitted
J3, J4: Conn_02x20_Odd_Even; PinHeader_2x20_P2.54mm_Horizontal
J5, J6: Conn_02x20_Odd_Even; PinSocket_2x20_P2.54mm_Horizontal
Q1, Q2, Q3, Q4, Q5, Q6, Q7, Q8, Q9, Q10, Q11, Q12, Q13, Q14, Q15, Q16, Q17, Q18, Q19, Q20, Q21, Q22, Q23, Q24, Q25, Q26, Q27, Q28, Q29, Q30, Q31, Q32, Q33, Q34, Q35, Q36, Q37, Q38, Q39, Q40: Q_PMOS_GDS; TO-251-3_Vertical_ThinPads
U1, U2, U3, U4, U5: 74HC595; DIP-16_W7.62mm
U6, U7, U8, U9, U10: TPIC6B595N; DIP-20_W7.62mm; MPN TPIC6B595N

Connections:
+5V: J1.1, J1.2, J2.1, J2.2, Q1.3 (S), Q2.3 (S), Q3.3 (S), Q4.3 (S), Q5.3 (S), Q6.3 (S), Q7.3 (S), Q8.3 (S), Q9.3 (S), Q10.3 (S), Q11.3 (S), Q12.3 (S), Q13.3 (S), Q14.3 (S), Q15.3 (S), Q16.3 (S), Q17.3 (S), Q18.3 (S), Q19.3 (S), Q20.3 (S), Q21.3 (S), Q22.3 (S), Q23.3 (S), Q24.3 (S), Q25.3 (S), Q26.3 (S), Q27.3 (S), Q28.3 (S), Q29.3 (S), Q30.3 (S), Q31.3 (S), Q32.3 (S), Q33.3 (S), Q34.3 (S), Q35.3 (S), Q36.3 (S), Q37.3 (S), Q38.3 (S), Q39.3 (S), Q40.3 (S), U1.16 (VCC), U2.16 (VCC), U3.16 (VCC), U4.16 (VCC), U5.16 (VCC), U6.2 (VCC), U7.2 (VCC), U8.2 (VCC), U9.2 (VCC), U10.2 (VCC)
/COLA0: DS1.13, DS6.13, DS11.13, DS16.13, DS21.13, J3.39, J6.40, Q1.2 (D)
/COLA1: DS1.3, DS6.3, DS11.3, DS16.3, DS21.3, J3.40, J6.39, Q2.2 (D)
/COLA2: DS1.4, DS6.4, DS11.4, DS16.4, DS21.4, J3.37, J6.38, Q3.2 (D)
/COLA3: DS1.10, DS6.10, DS11.10, DS16.10, DS21.10, J3.38, J6.37, Q4.2 (D)
/COLA4: DS1.6, DS6.6, DS11.6, DS16.6, DS21.6, J3.35, J6.36, Q5.2 (D)
/COLA5: DS1.11, DS6.11, DS11.11, DS16.11, DS21.11, J3.36, J6.35, Q6.2 (D)
/COLA6: DS1.15, DS6.15, DS11.15, DS16.15, DS21.15, J3.33, J6.34, Q7.2 (D)
/COLA7: DS1.16, DS6.16, DS11.16, DS16.16, DS21.16, J3.34, J6.33, Q8.2 (D)
/COLA8: DS2.13, DS7.13, DS12.13, DS17.13, DS22.13, J3.31, J6.32, Q9.2 (D)
/COLA9: DS2.3, DS7.3, DS12.3, DS17.3, DS22.3, J3.32, J6.31, Q10.2 (D)
/COLA10: DS2.4, DS7.4, DS12.4, DS17.4, DS22.4, J3.29, J6.30, Q11.2 (D)
/COLA11: DS2.10, DS7.10, DS12.10, DS17.10, DS22.10, J3.30, J6.29, Q12.2 (D)
/COLA12: DS2.6, DS7.6, DS12.6, DS17.6, DS22.6, J3.27, J6.28, Q13.2 (D)
/COLA13: DS2.11, DS7.11, DS12.11, DS17.11, DS22.11, J3.28, J6.27, Q14.2 (D)
/COLA14: DS2.15, DS7.15, DS12.15, DS17.15, DS22.15, J3.25, J6.26, Q15.2 (D)
/COLA15: DS2.16, DS7.16, DS12.16, DS17.16, DS22.16, J3.26, J6.25, Q16.2 (D)
/COLA16: DS3.13, DS8.13, DS13.13, DS18.13, DS23.13, J3.23, J6.24, Q17.2 (D)
/COLA17: DS3.3, DS8.3, DS13.3, DS18.3, DS23.3, J3.24, J6.23, Q18.2 (D)
/COLA18: DS3.4, DS8.4, DS13.4, DS18.4, DS23.4, J3.21, J6.22, Q19.2 (D)
/COLA19: DS3.10, DS8.10, DS13.10, DS18.10, DS23.10, J3.22, J6.21, Q20.2 (D)
/COLA20: DS3.6, DS8.6, DS13.6, DS18.6, DS23.6, J3.19, J6.20, Q21.2 (D)
/COLA21: DS3.11, DS8.11, DS13.11, DS18.11, DS23.11, J3.20, J6.19, Q22.2 (D)
/COLA22: DS3.15, DS8.15, DS13.15, DS18.15, DS23.15, J3.17, J6.18, Q23.2 (D)
/COLA23: DS3.16, DS8.16, DS13.16, DS18.16, DS23.16, J3.18, J6.17, Q24.2 (D)
/COLA24: DS4.13, DS9.13, DS14.13, DS19.13, DS24.13, J3.15, J6.16, Q25.2 (D)
/COLA25: DS4.3, DS9.3, DS14.3, DS19.3, DS24.3, J3.16, J6.15, Q26.2 (D)
/COLA26: DS4.4, DS9.4, DS14.4, DS19.4, DS24.4, J3.13, J6.14, Q27.2 (D)
/COLA27: DS4.10, DS9.10, DS14.10, DS19.10, DS24.10, J3.14, J6.13, Q28.2 (D)
/COLA28: DS4.6, DS9.6, DS14.6, DS19.6, DS24.6, J3.11, J6.12, Q29.2 (D)
/COLA29: DS4.11, DS9.11, DS14.11, DS19.11, DS24.11, J3.12, J6.11, Q30.2 (D)
/COLA30: DS4.15, DS9.15, DS14.15, DS19.15, DS24.15, J3.9, J6.10, Q31.2 (D)
/COLA31: DS4.16, DS9.16, DS14.16, DS19.16, DS24.16, J3.10, J6.9, Q32.2 (D)
/COLA32: DS5.13, DS10.13, DS15.13, DS20.13, DS25.13, J3.7, J6.8, Q33.2 (D)
/COLA33: DS5.3, DS10.3, DS15.3, DS20.3, DS25.3, J3.8, J6.7, Q34.2 (D)
/COLA34: DS5.4, DS10.4, DS15.4, DS20.4, DS25.4, J3.5, J6.6, Q35.2 (D)
/COLA35: DS5.10, DS10.10, DS15.10, DS20.10, DS25.10, J3.6, J6.5, Q36.2 (D)
/COLA36: DS5.6, DS10.6, DS15.6, DS20.6, DS25.6, J3.3, J6.4, Q37.2 (D)
/COLA37: DS5.11, DS10.11, DS15.11, DS20.11, DS25.11, J3.4, J6.3, Q38.2 (D)
/COLA38: DS5.15, DS10.15, DS15.15, DS20.15, DS25.15, J3.1, J6.2, Q39.2 (D)
/COLA39: DS5.16, DS10.16, DS15.16, DS20.16, DS25.16, J3.2, J6.1, Q40.2 (D)
/COLCLK: J2.4, U1.11 (SRCLK), U2.11 (SRCLK), U3.11 (SRCLK), U4.11 (SRCLK), U5.11 (SRCLK)
/COLCLR: J2.5, U1.10 (~SRCLR), U2.10 (~SRCLR), U3.10 (~SRCLR), U4.10 (~SRCLR), U5.10 (~SRCLR)
/COLDATIN: J2.3, U1.14 (SER)
/COLDATOUT: J2.8, U5.9 (QH')
/COLEN: J2.7, U1.13 (~OE), U2.13 (~OE), U3.13 (~OE), U4.13 (~OE), U5.13 (~OE)
/COLLATCH: J2.6, U1.12 (RCLK), U2.12 (RCLK), U3.12 (RCLK), U4.12 (RCLK), U5.12 (RCLK)
/ROWA0: DS1.9, DS2.9, DS3.9, DS4.9, DS5.9, J4.1, J5.2, U6.4 (DRAIN0)
/ROWA1: DS1.14, DS2.14, DS3.14, DS4.14, DS5.14, J4.2, J5.1, U6.5 (DRAIN1)
/ROWA2: DS1.8, DS2.8, DS3.8, DS4.8, DS5.8, J4.3, J5.4, U6.6 (DRAIN2)
/ROWA3: DS1.12, DS2.12, DS3.12, DS4.12, DS5.12, J4.4, J5.3, U6.7 (DRAIN3)
/ROWA4: DS1.1, DS2.1, DS3.1, DS4.1, DS5.1, J4.5, J5.6, U6.14 (DRAIN4)
/ROWA5: DS1.7, DS2.7, DS3.7, DS4.7, DS5.7, J4.6, J5.5, U6.15 (DRAIN5)
/ROWA6: DS1.2, DS2.2, DS3.2, DS4.2, DS5.2, J4.7, J5.8, U6.16 (DRAIN6)
/ROWA7: DS1.5, DS2.5, DS3.5, DS4.5, DS5.5, J4.8, J5.7, U6.17 (DRAIN7)
/ROWA8: DS6.9, DS7.9, DS8.9, DS9.9, DS10.9, J4.9, J5.10, U7.4 (DRAIN0)
/ROWA9: DS6.14, DS7.14, DS8.14, DS9.14, DS10.14, J4.10, J5.9, U7.5 (DRAIN1)
/ROWA10: DS6.8, DS7.8, DS8.8, DS9.8, DS10.8, J4.11, J5.12, U7.6 (DRAIN2)
/ROWA11: DS6.12, DS7.12, DS8.12, DS9.12, DS10.12, J4.12, J5.11, U7.7 (DRAIN3)
/ROWA12: DS6.1, DS7.1, DS8.1, DS9.1, DS10.1, J4.13, J5.14, U7.14 (DRAIN4)
/ROWA13: DS6.7, DS7.7, DS8.7, DS9.7, DS10.7, J4.14, J5.13, U7.15 (DRAIN5)
/ROWA14: DS6.2, DS7.2, DS8.2, DS9.2, DS10.2, J4.15, J5.16, U7.16 (DRAIN6)
/ROWA15: DS6.5, DS7.5, DS8.5, DS9.5, DS10.5, J4.16, J5.15, U7.17 (DRAIN7)
/ROWA16: DS11.9, DS12.9, DS13.9, DS14.9, DS15.9, J4.17, J5.18, U8.4 (DRAIN0)
/ROWA17: DS11.14, DS12.14, DS13.14, DS14.14, DS15.14, J4.18, J5.17, U8.5 (DRAIN1)
/ROWA18: DS11.8, DS12.8, DS13.8, DS14.8, DS15.8, J4.19, J5.20, U8.6 (DRAIN2)
/ROWA19: DS11.12, DS12.12, DS13.12, DS14.12, DS15.12, J4.20, J5.19, U8.7 (DRAIN3)
/ROWA20: DS11.1, DS12.1, DS13.1, DS14.1, DS15.1, J4.21, J5.22, U8.14 (DRAIN4)
/ROWA21: DS11.7, DS12.7, DS13.7, DS14.7, DS15.7, J4.22, J5.21, U8.15 (DRAIN5)
/ROWA22: DS11.2, DS12.2, DS13.2, DS14.2, DS15.2, J4.23, J5.24, U8.16 (DRAIN6)
/ROWA23: DS11.5, DS12.5, DS13.5, DS14.5, DS15.5, J4.24, J5.23, U8.17 (DRAIN7)
/ROWA24: DS16.9, DS17.9, DS18.9, DS19.9, DS20.9, J4.25, J5.26, U9.4 (DRAIN0)
/ROWA25: DS16.14, DS17.14, DS18.14, DS19.14, DS20.14, J4.26, J5.25, U9.5 (DRAIN1)
/ROWA26: DS16.8, DS17.8, DS18.8, DS19.8, DS20.8, J4.27, J5.28, U9.6 (DRAIN2)
/ROWA27: DS16.12, DS17.12, DS18.12, DS19.12, DS20.12, J4.28, J5.27, U9.7 (DRAIN3)
/ROWA28: DS16.1, DS17.1, DS18.1, DS19.1, DS20.1, J4.29, J5.30, U9.14 (DRAIN4)
/ROWA29: DS16.7, DS17.7, DS18.7, DS19.7, DS20.7, J4.30, J5.29, U9.15 (DRAIN5)
/ROWA30: DS16.2, DS17.2, DS18.2, DS19.2, DS20.2, J4.31, J5.32, U9.16 (DRAIN6)
/ROWA31: DS16.5, DS17.5, DS18.5, DS19.5, DS20.5, J4.32, J5.31, U9.17 (DRAIN7)
/ROWA32: DS21.9, DS22.9, DS23.9, DS24.9, DS25.9, J4.33, J5.34, U10.4 (DRAIN0)
/ROWA33: DS21.14, DS22.14, DS23.14, DS24.14, DS25.14, J4.34, J5.33, U10.5 (DRAIN1)
/ROWA34: DS21.8, DS22.8, DS23.8, DS24.8, DS25.8, J4.35, J5.36, U10.6 (DRAIN2)
/ROWA35: DS21.12, DS22.12, DS23.12, DS24.12, DS25.12, J4.36, J5.35, U10.7 (DRAIN3)
/ROWA36: DS21.1, DS22.1, DS23.1, DS24.1, DS25.1, J4.37, J5.38, U10.14 (DRAIN4)
/ROWA37: DS21.7, DS22.7, DS23.7, DS24.7, DS25.7, J4.38, J5.37, U10.15 (DRAIN5)
/ROWA38: DS21.2, DS22.2, DS23.2, DS24.2, DS25.2, J4.39, J5.40, U10.16 (DRAIN6)
/ROWA39: DS21.5, DS22.5, DS23.5, DS24.5, DS25.5, J4.40, J5.39, U10.17 (DRAIN7)
/ROWCLK: J1.3, U6.12 (RCK), U7.12 (RCK), U8.12 (RCK), U9.12 (RCK), U10.12 (RCK)
/ROWCLR: J1.4, U6.8 (~SRCLR), U7.8 (~SRCLR), U8.8 (~SRCLR), U9.8 (~SRCLR), U10.8 (~SRCLR)
/ROWDAT0: J1.7, U6.3 (SER_IN)
/ROWDAT1: J1.8, U7.3 (SER_IN)
/ROWDAT2: J1.9, U8.3 (SER_IN)
/ROWDAT3: J1.10, U9.3 (SER_IN)
/ROWDAT4: J1.11, U10.3 (SER_IN)
/ROWEN: J1.6, U6.9 (~G), U7.9 (~G), U8.9 (~G), U9.9 (~G), U10.9 (~G)
/ROWLATCH: J1.5, U6.13 (SRCK), U7.13 (SRCK), U8.13 (SRCK), U9.13 (SRCK), U10.13 (SRCK)
GND: J1.12, J1.13, J2.9, J2.10, U1.8 (GND), U2.8 (GND), U3.8 (GND), U4.8 (GND), U5.8 (GND), U6.10 (GND_2), U6.11 (GND), U6.19 (GND_3), U7.10 (GND_2), U7.11 (GND), U7.19 (GND_3), U8.10 (GND_2), U8.11 (GND), U8.19 (GND_3), U9.10 (GND_2), U9.11 (GND), U9.19 (GND_3), U10.10 (GND_2), U10.11 (GND), U10.19 (GND_3)
unnamed: Q1.1 (G), U1.15 (QA)
unnamed: Q2.1 (G), U1.1 (QB)
unnamed: Q3.1 (G), U1.2 (QC)
unnamed: Q4.1 (G), U1.3 (QD)
unnamed: Q5.1 (G), U1.4 (QE)
unnamed: Q6.1 (G), U1.5 (QF)
unnamed: Q7.1 (G), U1.6 (QG)
unnamed: Q8.1 (G), U1.7 (QH)
unnamed: Q9.1 (G), U2.15 (QA)
unnamed: Q10.1 (G), U2.1 (QB)
unnamed: Q11.1 (G), U2.2 (QC)
unnamed: Q12.1 (G), U2.3 (QD)
unnamed: Q13.1 (G), U2.4 (QE)
unnamed: Q14.1 (G), U2.5 (QF)
unnamed: Q15.1 (G), U2.6 (QG)
unnamed: Q16.1 (G), U2.7 (QH)
unnamed: Q17.1 (G), U3.15 (QA)
unnamed: Q18.1 (G), U3.1 (QB)
unnamed: Q19.1 (G), U3.2 (QC)
unnamed: Q20.1 (G), U3.3 (QD)
unnamed: Q21.1 (G), U3.4 (QE)
unnamed: Q22.1 (G), U3.5 (QF)
unnamed: Q23.1 (G), U3.6 (QG)
unnamed: Q24.1 (G), U3.7 (QH)
unnamed: Q25.1 (G), U4.15 (QA)
unnamed: Q26.1 (G), U4.1 (QB)
unnamed: Q27.1 (G), U4.2 (QC)
unnamed: Q28.1 (G), U4.3 (QD)
unnamed: Q29.1 (G), U4.4 (QE)
unnamed: Q30.1 (G), U4.5 (QF)
unnamed: Q31.1 (G), U4.6 (QG)
unnamed: Q32.1 (G), U4.7 (QH)
unnamed: Q33.1 (G), U5.15 (QA)
unnamed: Q34.1 (G), U5.1 (QB)
unnamed: Q35.1 (G), U5.2 (QC)
unnamed: Q36.1 (G), U5.3 (QD)
unnamed: Q37.1 (G), U5.4 (QE)
unnamed: Q38.1 (G), U5.5 (QF)
unnamed: Q39.1 (G), U5.6 (QG)
unnamed: Q40.1 (G), U5.7 (QH)
unnamed: U1.9 (QH'), U2.14 (SER)
unnamed: U2.9 (QH'), U3.14 (SER)
unnamed: U3.9 (QH'), U4.14 (SER)
unnamed: U4.9 (QH'), U5.14 (SER)

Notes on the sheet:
connect logical power supplies
row/column driving circuitry will only be populated in 1 board per row/column
control connections
led matrix lines

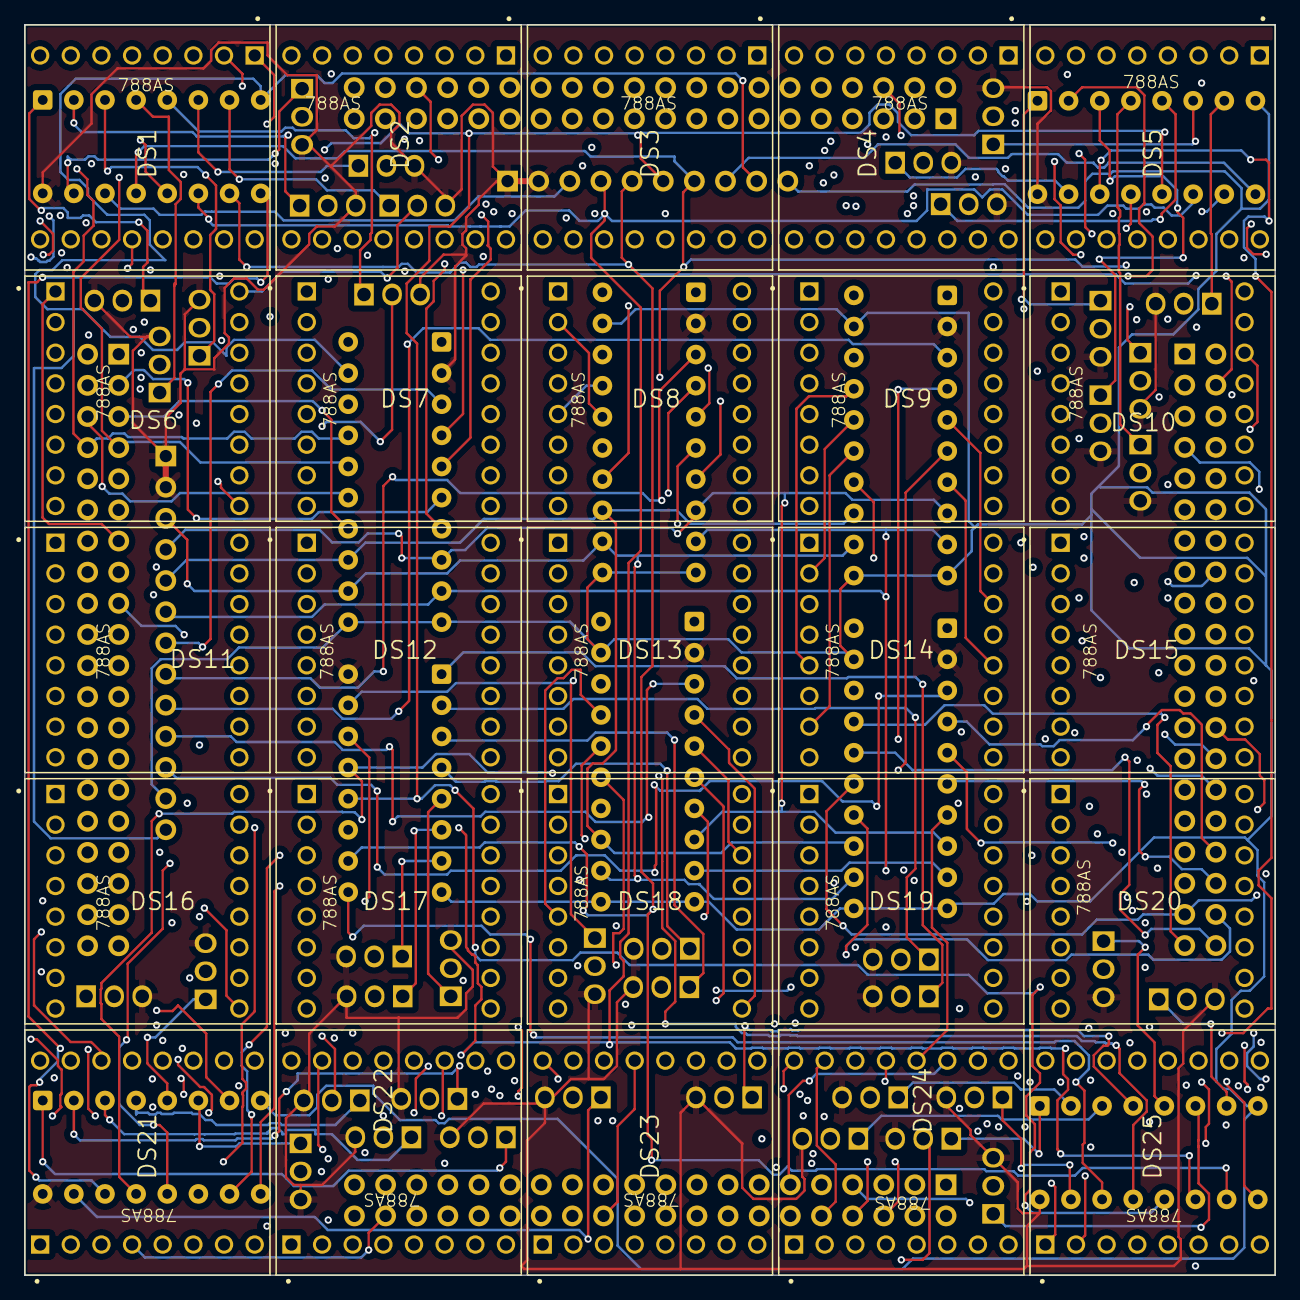
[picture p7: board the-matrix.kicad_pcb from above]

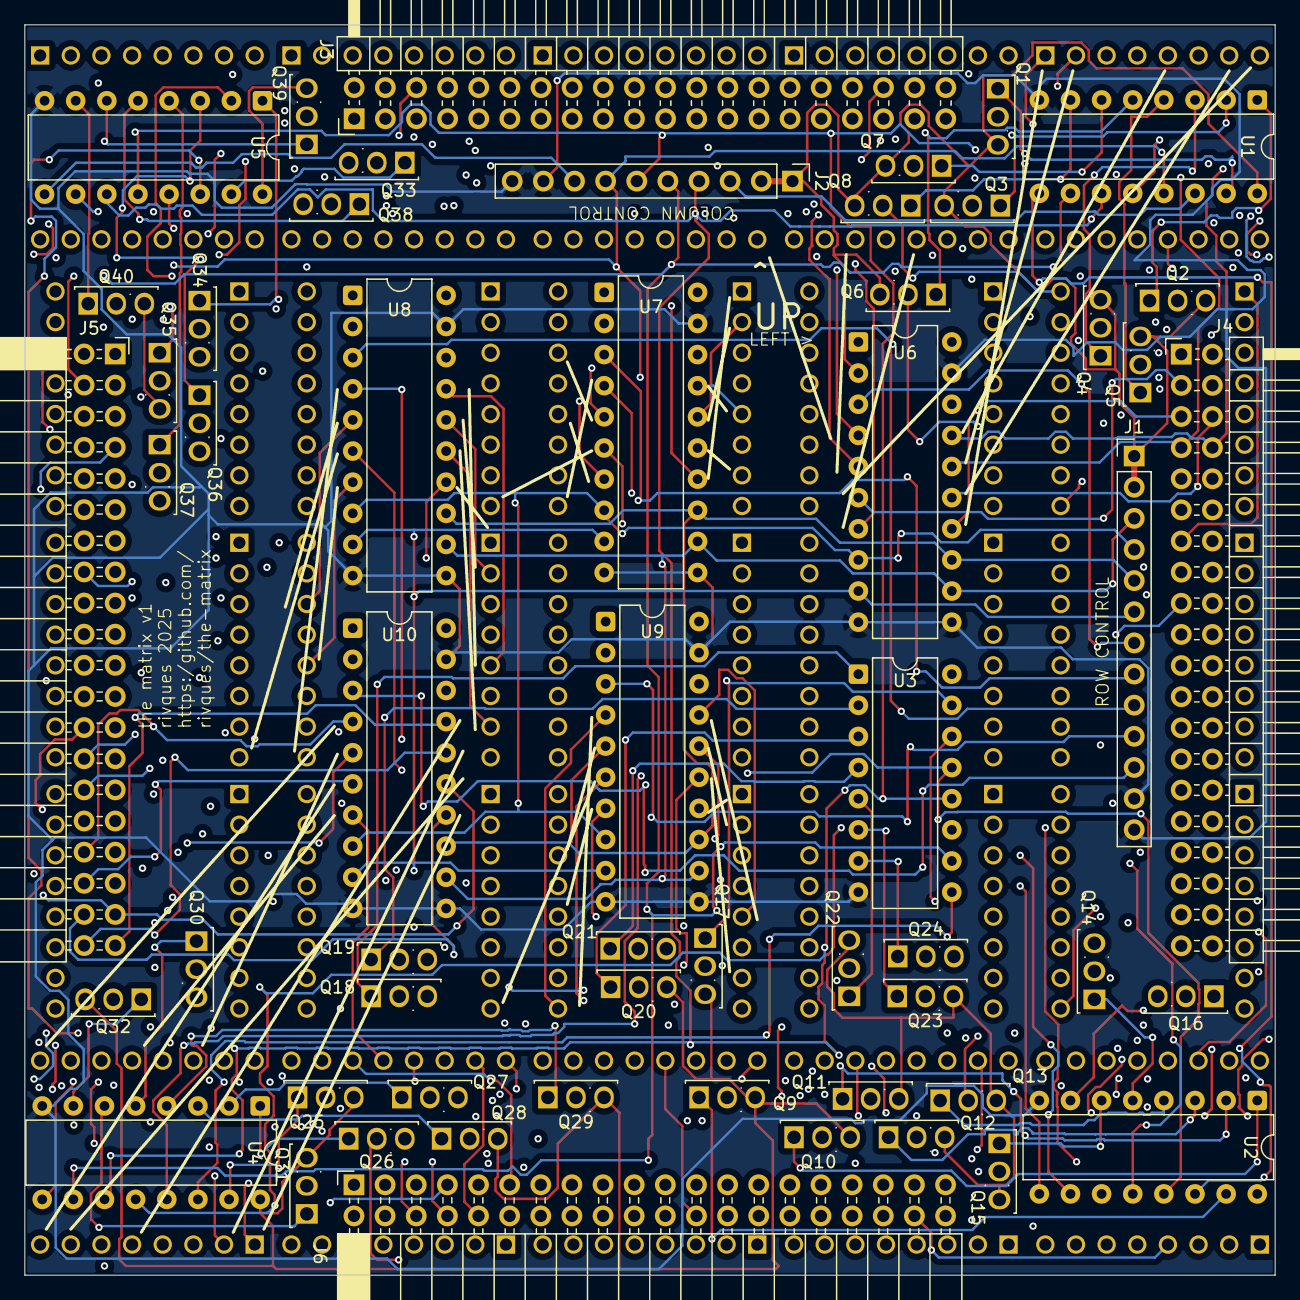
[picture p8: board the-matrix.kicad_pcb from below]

Board: 4 copper layers, 102.0 x 102.0 mm, 81 parts (56 on the bottom side), 141 nets.

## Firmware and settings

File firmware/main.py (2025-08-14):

from machine import Pin, PWM, freq
import utime
import time
import rp2
import math
import framebuf
import gc
import micropython
from array import array
#freq(25_000_000)  # Set the CPU frequency to 18 MHz for better timing control
SLOWDOWN_CONST = 1
NUM_COLS = 40

# out_init is for 15xrowdat+coldat, set_init is latch, clear, rowclk, colclk
@rp2.asm_pio(out_init=[rp2.PIO.OUT_LOW] * 16, set_init=[rp2.PIO.OUT_LOW, rp2.PIO.OUT_HIGH, rp2.PIO.OUT_LOW, rp2.PIO.OUT_LOW], autopull=True, pull_thresh=16, fifo_join=rp2.PIO.JOIN_TX)
def pio_disp_routine():
    # this function shifts out a single column. It's expecting data to be constantly fed to it via DMA.
    # It consumes 16-bit words (though the FIFO is filled in 32-bit mode), where the first 15 bits are row data and the last bit is column data.
    # A single full column (120 pixels) is 16 bytes of data.

    # Shift 8 times out to the row data pins, pulsing the row clock each time.
    out(pins, 16).delay(1)
    set(pins, 0b1110).delay(1) # just the first time, pulse the column clock
    set(pins, 0b0010).delay(1) # once
    out(pins, 16).delay(1)
    set(pins, 0b0110).delay(1)
    set(pins, 0b0010).delay(1) # twice
    out(pins, 16).delay(1)
    set(pins, 0b0110).delay(1)
    set(pins, 0b0010).delay(1) # thrice
    out(pins, 16).delay(1)
    set(pins, 0b0110).delay(1)
    set(pins, 0b0010).delay(1) # quadrice
    out(pins, 16).delay(1)
    set(pins, 0b0110).delay(1)
    set(pins, 0b0010).delay(1) # quintice
    out(pins, 16).delay(1)
    set(pins, 0b0110).delay(1)
    set(pins, 0b0010).delay(1) # sextice
    out(pins, 16).delay(1)
    set(pins, 0b0110).delay(1)
    set(pins, 0b0010).delay(1) # septice
    out(pins, 16).delay(1)
    set(pins, 0b0110).delay(1)
    set(pins, 0b0010).delay(1) # octice

    # latch the data
    set(pins, 0b0011).delay(1) # latch pin high
    set(pins, 0b0010).delay(1) # latch pin low

def get_modcoords(x, y):
    # get the coordinates of the module that contains this pixel
    # each module is 40x40
    mod_x = x // 40
    mod_y = y // 40
    return mod_x, mod_y

def get_8x8_coords_modlocal(x, y):
    # get the coordinates of the 8x8 module that contains this pixel, relative to the module of the pixel
    local_x = x % 40
    local_y = y % 40
    return local_x // 8, local_y // 8

def get_coords_8x8local(x, y):
    # get the coordinates of the 8x8 module that contains this pixel, relative to the 8x8 module
    local_x = x % 8
    local_y = y % 8
    return local_x, local_y

print("Generating coordinate transformation LUT...")
start_time = utime.ticks_ms()
def coord_xform(x, y):
    # TODO: handle row interlacing on alternating modules

    # 8x8-specific rotations
    x_8x8_mod, y_8x8_mod = get_8x8_coords_modlocal(x, y)
    x_8x8_local, y_8x8_local = get_coords_8x8local(x, y)
    # 1-3: rotate 90 clockwise in its 8x8 grid
    # NOTE: this breaks on rows > 40, but works for now
    if y_8x8_mod >= 1 and y_8x8_mod <= 3:
        x = x_8x8_mod * 8 + (7 - y_8x8_local)
        y = y_8x8_mod * 8 + x_8x8_local
    # 4: rotate 180 degrees in its 8x8 grid
    elif y_8x8_mod == 4:
        x = x_8x8_mod * 8 + (7 - x_8x8_local)
        y = y_8x8_mod * 8 + (7 - y_8x8_local)     

    return y * 120 + x

coord_xform_lut = array('H')
for x in range(120):
    for y in range(120):
        coord_xform_lut.append(coord_xform(x, y))
print(f"Generated coordinate transformation LUT in {utime.ticks_diff(utime.ticks_ms(), start_time)} ms")

@micropython.native
def compute_frame(pio_data, buffer):
    raw_pix_idx = 0
    for col in range(120):
        words = array('H', [0 if col == 0 else 0x8000, 0x8000, 0x8000, 0x8000, 0x8000, 0x8000, 0x8000, 0x8000])  # 8 words per column
        # if col == 0:
        #     postarray = utime.ticks_us()
            
        for row_reg in range(15):
            # runs once per row shift register
            for word_num in range(8):
                # runs 8 (times 15) times per column, once per PIO input word
                # figure out which coordinates we actually want data for
                pix_idx = coord_xform_lut[raw_pix_idx] # col + (row_reg * 8 + word_num) * 120] # y = (row_reg * 8 + word_num)
                
                bit = (buffer[pix_idx // 8] & (1 << pix_idx % 8)) >> pix_idx % 8
                # put the bit in the correct position in the word
                words[word_num] |= (bit << row_reg)
                raw_pix_idx += 1

        # if col == 0:
        #     postwordgen = utime.ticks_us()
        # put each byte of each word in the PIO data array, little-endian
        pio_data.extend(words)
        # if col == 0:
        #     postextend = utime.ticks_us()

@micropython.native
def arrcopy(dest, src, length):
    for i in range(length):
        dest[i] = src[i]

def draw_frame(fbuf):
    fbuf.fill(0)
    (year, month, mday, hour, minute, second, weekday, yearday) = time.localtime()
    pi = 3.14159

    # hour ticks
    for i in range(12):
        theta = i * pi / 6
        rmin = 17
        rmax = 20
        for r in range(rmin, rmax):
            x = int(r * math.cos(theta) + 20)
            y = int(r * math.sin(theta) + 20)
            fbuf.pixel(x, y, 1)
    
    # seconds progress
    thetamax = (second / 60) * 2 * pi
    for thetadeg in range(360):
        theta = thetadeg * pi / 180
        if theta <= thetamax:
            x = int(20 * math.cos(theta - pi/2) + 20)
            y = int(20 * math.sin(theta - pi/2) + 20)
            fbuf.pixel(x, y, 1)
    
    # hours text
    hour_string = f"{hour:02}"
    fbuf.text(hour_string[0], 4, 16, 1)
    fbuf.text(hour_string[1], 11, 16, 1)
    # colon
    fbuf.rect(19, 17, 2, 2, 1)
    fbuf.rect(19, 21, 2, 2, 1)
    # minutes text
    minute_string = f"{minute:02}"
    fbuf.text(minute_string[0], 21, 16, 1)
    fbuf.text(minute_string[1], 28, 16, 1)
    # seconds text
    second_string = f"{second:02}"
    fbuf.text(second_string, 12, 25, 1)
    # weekday text
    weekdays = ["Mon", "Tue", "Wed", "Thu", "Fri", "Sat", "Sun"]
    fbuf.text(weekdays[weekday], 8, 8, 1)

class Matrix:
    def __init__(self):
        self.rowdat_pins = [Pin(1, Pin.OUT)]
        self.coldat_pin = Pin(16, Pin.OUT)
        self.latch_pin = Pin(17, Pin.OUT) # NOTE: The pin labels for ROWLATCH and ROWCLK are the wrong way around. Because of this, this pin should connect to the wires labeled ROWCLK and COLLATCH.
        self.latch_pin.value(0)
        self.clear_pin = Pin(18, Pin.OUT) # active low
        self.clear_pin.value(1)
        self.rowclk_pin = Pin(19, Pin.OUT) # NOTE: Because of the above swap, this pin should connect to the wire labeled ROWLATCH.
        self.rowclk_pin.value(0)
        self.colclk_pin = Pin(20, Pin.OUT)
        self.colclk_pin.value(0)
        self.rowen_pin = PWM(Pin(0, Pin.OUT), freq=10_000_000, duty_u16=0)
        self.rowen_pin.duty_u16(65535) # disable output for now
        self.brightness = 0.5

        # clear registers
        self.clear_pin.value(0)
        utime.sleep_ms(2)
        self.clear_pin.value(1)

        # shift ones through the columns
        self.coldat_pin.value(1)
        for _ in range(NUM_COLS):
            self.colclk_pin.value(1)
            utime.sleep_us(10)
            self.colclk_pin.value(0)
            utime.sleep_us(10)
        self.latch_pin.value(1)
        utime.sleep_us(10)
        self.latch_pin.value(0)

    def display_frame(self, frame):
        try: 
            # print("Displaying frame...")
            # the frame is a 2D list of bytes. each byte represents 8 pixels in a column.
            # to display a frame:
            # for each column:
            #  shift out the rows (8 pixels to a row pin)
            #  if it's the first column, shift a 0 onto the column data, otherwise, shift a 1
            #  latch the data

            # enable output
            self.rowen_pin.duty_u16(int((1-self.brightness) * 65535))
            self.brightness += 0.01
            if self.brightness > 0.7:
                self.brightness = 0.0

            for col in range(len(frame)):
                # print(f"Processing column {col}")
                # runs once per column
                for row in range(8):
                    # runs 8 times per column (once per row SR size)
                    for i, pin in enumerate(self.rowdat_pins):
                        # runs once per row per column
                        bit = (frame[col][i] & (1 << (row % 8))) != 0
                        # print(f"  Row {row}, Pin {i}: {'ON' if bit else 'OFF'}")
                        if bit:
                            pin.value(1)
                        else:
                            pin.value(0)
                    utime.sleep_us(5*SLOWDOWN_CONST)
                    # shift out the row data
                    self.rowclk_pin.value(1)
                    utime.sleep_us(10*SLOWDOWN_CONST)
                    self.rowclk_pin.value(0)
                    utime.sleep_us(10*SLOWDOWN_CONST)
                # shift out the column data
                if col == 0:
                    self.coldat_pin.value(0)
                    # print("  Setting coldat pin LOW for first column")
                else:
                    self.coldat_pin.value(1)
                    # print("  Setting coldat pin HIGH")
                utime.sleep_us(5*SLOWDOWN_CONST)
                self.colclk_pin.value(1)
                utime.sleep_us(10*SLOWDOWN_CONST)
                self.colclk_pin.value(0)
                utime.sleep_us(10*SLOWDOWN_CONST)
                # latch the data
                self.latch_pin.value(1)
                utime.sleep_us(10*SLOWDOWN_CONST)
                self.latch_pin.value(0)
                # print(f"  Latched column {col}")
            utime.sleep_us(235*SLOWDOWN_CONST)
            # print("Frame displayed.")
        finally:
            # disable output
            self.rowen_pin.duty_u16(65535)
            # print("Output disabled.")
    
    def display_pio(self, frame, pio_freq):
        # configure the PIO to display the given frame.
        # As a first step, convert the frame to the format PIO is expecting.
        # The frame is given as a 2D list of bytes, where each top-level list is a column and each byte is 8 pixels in that column.
        # The PIO expects 8 16-bit words per column, where each the LS 15 bits in row i are data for row % 8 == i in that column, and the MS bit is 1 at the first word in the column.\

        pio_data = []
        for col in range(len(frame)):
            # runs once per column
            words = [1 << 15] * 8 # 8 words per column
            if col == 0:
                words[0] = 0 # first column has a 0 in the MS bit of the first word

            for word_num in range(len(words)):
                # runs 8 times per column, once per PIO input word
                for row_reg in range(15):
                    # runs once per row shift register
                    if row_reg < 1:
                        bit = (frame[col][row_reg] & (1 << word_num)) != 0
                    else:
                        bit = 0 # we only have 1 row SR for now
                    # put the bit in the correct position in the word    
                    words[word_num] |= (bit << row_reg)
            
            # put each byte of each word in the PIO data array, little-endian
            print(f"Words for column {col}:")
            for word in words:
                print(f"  {word:016b}", end=' ')
                pio_data.append(word & 0xFF)
                pio_data.append((word >> 8) & 0xFF)
            print()
        
        raw_data = bytearray(pio_data)
        print(f"Raw PIO data: {raw_data.hex()}")
        self.pio = rp2.StateMachine(0, pio_disp_routine, out_base=self.rowdat_pins[0], set_base=self.latch_pin, freq=pio_freq)
        self.dma = rp2.DMA()
        config = self.dma.pack_ctrl(
            inc_write=False, # don't increment the write addr, we're writing to the peripheral
            # ring_size=8, # 16 bytes per column, 8 columns (TODO: increment 3 when more columns are added)
            # ring_sel=False, # increment the read address
            treq_sel=0, # dreq on the TX FIFO of the first PIO state machine
            size=1, # 16-bit transfers
            bswap=False, # no byte swapping
            irq_quiet=False, # irq on completion
        )
        self.dma.config(read=raw_data, write=self.pio, ctrl=config, count=8*NUM_COLS, trigger=False)
        self.dma.irq(lambda _: self.dma.config(read=raw_data, write=self.pio, ctrl=config, count=8*NUM_COLS, trigger=True), hard=True)
        self.pio.active(1)
        self.dma.active(1)
    
    def display_pio_framebuf(self, framebuffer, pio_freq):
        # display a frame buffer using PIO
        # the buffer is a linear list of bytes, where each byte represents 8 pixels in a row, and the LSB is the rightmost pixel in an 8-pixel row (MONO_HLSB format).
        # the PIO expects 8 16-bit words per column, where each the LS 15 bits in row i are data for row % 8 == i in that column, and the MS bit is 1 at the first word in the column.
        
        start_time = utime.ticks_ms()
        print(f"free memory before preparing PIO data: {gc.mem_free()//1024} KiB")
        gc.collect()  # collect garbage to free up memory
        print(f"free memory after garbage collection: {gc.mem_free()//1024} KiB")

        pio_data = array('H', [])  # use an array of unsigned shorts for PIO data
        compute_frame(pio_data, framebuffer)

        # start_us = utime.ticks_us()
        # postarray=0
        # postwordgen=0
        # postextend=0
        
        # print(f"Col 0 prep times: array={utime.ticks_diff(postarray, start_us)} us, wordgen={utime.ticks_diff(postwordgen, postarray)} us, extend={utime.ticks_diff(postextend, postwordgen)} us, total={utime.ticks_diff(postextend, start_us)} us")
        print(f"Free memory after preparing PIO data: {gc.mem_free()//1024} KiB")
        gc.collect()  # collect garbage to free up memory
        print(f"Free memory after garbage collection: {gc.mem_free()//1024} KiB")
        print(f"Time to prepare PIO data: {utime.ticks_diff(utime.ticks_ms(), start_time)} ms")
        print(f"Raw PIO data: {memoryview(pio_data).hex()}")
        self.pio = rp2.StateMachine(0, pio_disp_routine, out_base=self.rowdat_pins[0], set_base=self.latch_pin, freq=pio_freq)
        print(f"time to create PIO state machine: {utime.ticks_diff(utime.ticks_ms(), start_time)} ms")
        self.dma = rp2.DMA()
        config = self.dma.pack_ctrl(
            inc_write=False, # don't increment the write addr, we're writing to the peripheral
            # ring_size=8, # 16 bytes per column, 8 columns (TODO: increment 3 when more columns are added)
            # ring_sel=False, # increment the read address
            treq_sel=0, # dreq on the TX FIFO of the first PIO state machine
            size=1, # 16-bit transfers
            bswap=False, # no byte swapping
            irq_quiet=False, # irq on completion
        )
        self.dma.config(read=pio_data, write=self.pio, ctrl=config, count=len(pio_data), trigger=False)
        self.dma.irq(lambda _: self.dma.config(read=pio_data, write=self.pio, ctrl=config, count=len(pio_data), trigger=True), hard=True)
        print(f"time to configure DMA: {utime.ticks_diff(utime.ticks_ms(), start_time)} ms")
        self.pio.active(1)
        self.dma.active(1)
        print(f"time to activate PIO and DMA: {utime.ticks_diff(utime.ticks_ms(), start_time)} ms")
    
    def display_raw_data(self, pio_data, pio_freq):
        # display a frame buffer using PIO
        # the buffer is a linear list of bytes, where each byte represents 8 pixels in a row, and the LSB is the rightmost pixel in an 8-pixel row (MONO_HLSB format).
        # the PIO expects 8 16-bit words per column, where each the LS 15 bits in row i are data for row % 8 == i in that column, and the MS bit is 1 at the first word in the column.
        
        start_time = utime.ticks_ms()
        print(f"free memory before preparing PIO data: {gc.mem_free()//1024} KiB")
        gc.collect()  # collect garbage to free up memory
        print(f"Free memory after garbage collection: {gc.mem_free()//1024} KiB")
        print(f"Time to prepare PIO data: {utime.ticks_diff(utime.ticks_ms(), start_time)} ms")
        print(f"Raw PIO data: {memoryview(pio_data).hex()}")
        self.pio = rp2.StateMachine(0, pio_disp_routine, out_base=self.rowdat_pins[0], set_base=self.latch_pin, freq=pio_freq)
        print(f"time to create PIO state machine: {utime.ticks_diff(utime.ticks_ms(), start_time)} ms")
        self.dma = rp2.DMA()
        config = self.dma.pack_ctrl(
            inc_write=False, # don't increment the write addr, we're writing to the peripheral
            # ring_size=8, # 16 bytes per column, 8 columns (TODO: increment 3 when more columns are added)
            # ring_sel=False, # increment the read address
            treq_sel=0, # dreq on the TX FIFO of the first PIO state machine
            size=1, # 16-bit transfers
            bswap=False, # no byte swapping
            irq_quiet=False, # irq on completion
        )
        self.dma.config(read=pio_data, write=self.pio, ctrl=config, count=len(pio_data), trigger=False)
        self.dma.irq(lambda _: self.dma.config(read=pio_data, write=self.pio, ctrl=config, count=len(pio_data), trigger=True), hard=True)
        print(f"time to configure DMA: {utime.ticks_diff(utime.ticks_ms(), start_time)} ms")
        self.pio.active(1)
        self.dma.active(1)
        print(f"time to activate PIO and DMA: {utime.ticks_diff(utime.ticks_ms(), start_time)} ms")

        

matrix = Matrix()

buf_raw = bytearray(120 * 120 // 8) # 120x120 pixels, 8 pixels per byte
fbuf = framebuf.FrameBuffer(buf_raw, 120, 120, framebuf.MONO_HLSB)

fbuf.fill(1)  # Clear the frame buffer
#fbuf.fill_rect(0, 0, 8, 8, 1)
fbuf.text("12345", 0, 0, 0)
fbuf.text("67890", 0, 8, 0)
fbuf.text("ABCDE", 0, 16, 0)
fbuf.text("FGHIJ", 0, 24, 0)
fbuf.text("KLMNO", 0, 32, 0)

# print out the framebuffer
print("Frame buffer content:")
for y in range(40):
    row_data = []
    for x in range(40):
        byte = fbuf.pixel(x, y)
        row_data.append("#" if byte else ".")
    print("".join(row_data))

matrix.rowen_pin.duty_u16(32000)

pio_freq = 400_000  # PIO frequency
pio_data_pre = array('H', [])
compute_frame(pio_data_pre, buf_raw)
pio_data = array('H', pio_data_pre)
print(f"{len(pio_data_pre)=}, {len(pio_data)=}")
matrix.display_raw_data(pio_data, pio_freq)
try:
    while True:
        frame_start_time = utime.ticks_ms()
        utime.sleep_ms(300)
        print(f"{matrix.pio.tx_fifo()} bytes on the TX FIFO")
        print(f"State machine active: {matrix.pio.active()}")
        print(f"DMA active: {matrix.dma.active()}")
        print(f"Processor frequency: {freq()} Hz")
        print(f"PIO frequency: {pio_freq} Hz")

        
        draw_frame(fbuf)
        pio_data_pre = array('H', [])
        compute_frame(pio_data_pre, buf_raw)
        print(f"Took {utime.ticks_diff(utime.ticks_ms(), frame_start_time)} ms to compute new frame")
        # copy pio data pre into pio data
        # dma = rp2.DMA()
        # config = dma.pack_ctrl()
        # dma.config(read=pio_data_pre, write=pio_data, ctrl=config, count=len(pio_data_pre)//4, trigger=True) 
        # print("DMA configured.")
        # while dma.active():
        #     utime.sleep_ms(10)
        # print("DMA completed.")
        while utime.ticks_diff(utime.ticks_ms(), frame_start_time) < 1000:
            pass
        arrcopy(pio_data, pio_data_pre, len(pio_data_pre))
        # print("Copied PIO data to display buffer")


except:
    matrix.dma.active(0)
    matrix.pio.active(0)
    matrix.dma.close()
    matrix.rowen_pin.duty_u16(65535)  # disable output
    print("DMA and PIO deactivated.")
    raise

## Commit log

2025-05-28 quick commit so i can add a photo on gh
    [the-matrix.kicad_pcb, the-matrix.kicad_sch]
2025-05-28 one more session for today
    [the-matrix.kicad_pcb, the-matrix.kicad_sch]
2025-05-28 it is not in fact cheaper from digikey
    [the-matrix.kicad_pcb]
2025-05-28 an amount of progress on routing
    [the-matrix.kicad_pcb, the-matrix.kicad_sch]
2025-05-28 route the matrix
    [the-matrix.kicad_pcb, the-matrix.kicad_sch]
2025-05-28 more routing!
    [the-matrix.kicad_pcb]
2025-05-28 column connectors wired
    [the-matrix.kicad_pcb]
2025-05-28 route the left connector
    [the-matrix.kicad_pcb]
2025-05-29 connectors complete!
    [the-matrix.kicad_pcb]
2025-05-29 start connecting the shift registers
    [the-matrix.kicad_pcb]
2025-05-29 just starting to route power
    [the-matrix.kicad_pcb]
2025-05-29 almost there, but when did i delete a display?
    [the-matrix.kicad_pcb]
2025-05-29 dw the display is fine
    [the-matrix.kicad_pcb]
2025-05-29 pcb complete!
    [the-matrix.kicad_pcb]
2025-05-29 before resistor silkscreen reexport
    [the-matrix-bom.csv, the-matrix.kicad_pcb]
2025-05-29 re-evaluate BOM
2025-05-29 prepare for submission!
    [BOM.csv]
2025-06-06 Add BOM to README.md
2025-06-06 Add schematic to README.md
2025-06-11 counting is hard :’)
2025-06-26 cad work
2025-06-30 start assembly!
2025-07-01 soldered final resistors (was really annoying)
2025-07-01 add some tools i used while soldering
    [display_soldering_tool.step, mosfet tool.step]
2025-07-10 optimize frame computation routine
